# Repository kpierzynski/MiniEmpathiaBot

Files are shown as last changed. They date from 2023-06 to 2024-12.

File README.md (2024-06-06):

# RoboBond
## Empatyczny rój robotów

| Mobilny rój robotów |
|:-:|
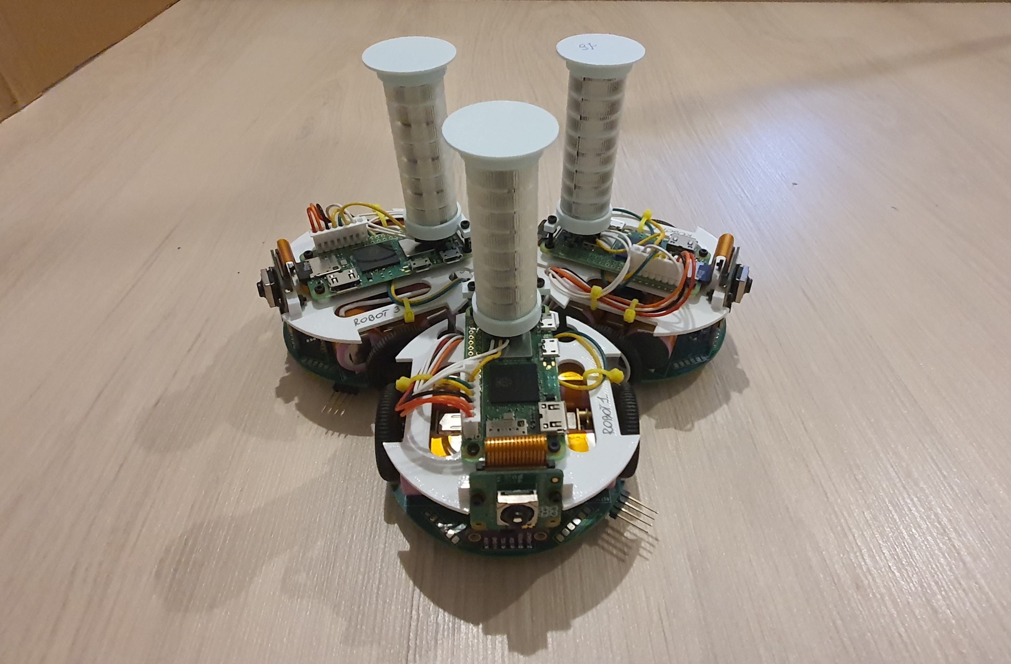
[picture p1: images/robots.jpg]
2nd_gen_robot
||

### Motywacja
Celem projektu jest opracowanie drugiej generacji empatycznego roju robotów, umożliwiającej przeprowadzanie fizycznych eksperymentów wygodniej, szybciej i na szerszą skalę. Celem badawczym jest analiza algorytmów sztucznej empatii na zminiaturyzowanej generacji roju robotów.

### Opis
Projekt "Rój Empatycznych Robotów" polega na stworzeniu zaawansowanej grupy robotów, która będzie zdolna do interakcji i współpracy, odzwierciedlając przy tym podstawowe instynkty ludzkie, aby efektywnie rozwiązywać zadane problemy. Przyjęcie perspektywy innej osoby i próba zrozumienia jej punktu widzenia znaczenie poprawia współpracę oraz wpływa na osiągnięte wyniki. Roboty dzięki modułowi sztucznej empatii, będą mogły podejmować decyzje w oparciu o stan sąsiednich robotów, pozwala to na stworzenie bardziej efektywnych strategii i szybsze osiągnięcie globalnego celu.

Do przeprowadzenia eksperymentów walidujących użycie algorytmów sztucznej empatii, stworzone zostały dwa symulatory oraz fizyczna platforma mobilnych robotów.

### Zastosowania
- Platforma badawcza dla naukowców do weryfikacji nowych algorytmów sztucznej empatii,
- Środowisko dla nauczycieli wspierające dydaktykę z zakresu sztucznej inteligencji,
- Infrastruktura do testowania nowych ścieżek automatyzacji i robotyzacji w przedsiębiorstwach,
- ... oraz wiele innych.

### Zawartość
W repozytorium znajdują się:
- Symulatory
    - `simulators/RL_ROS_Robots`
    - `simulators/Simpathy`
- Projekt mobilnych robotów
    - `kicad_workspace/bottom` - schemat elektroniczny PCB oraz opis konstrukcji
    - `code/STM32` - kod źródłowy dolnego niskopoziomowego mikrokontrolera robota
    - `code/PI` - kod źródłowy implementujący scenariusz empatyczny 
    - `cad_models` - modele 3d części robota

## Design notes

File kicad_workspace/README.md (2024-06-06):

# Empatyczny robot, iteracja druga

## Obecna konstrukcja PCB
Widok gory | Widok spodu
-- | --
top_view | bottom_view

## Architektura robota
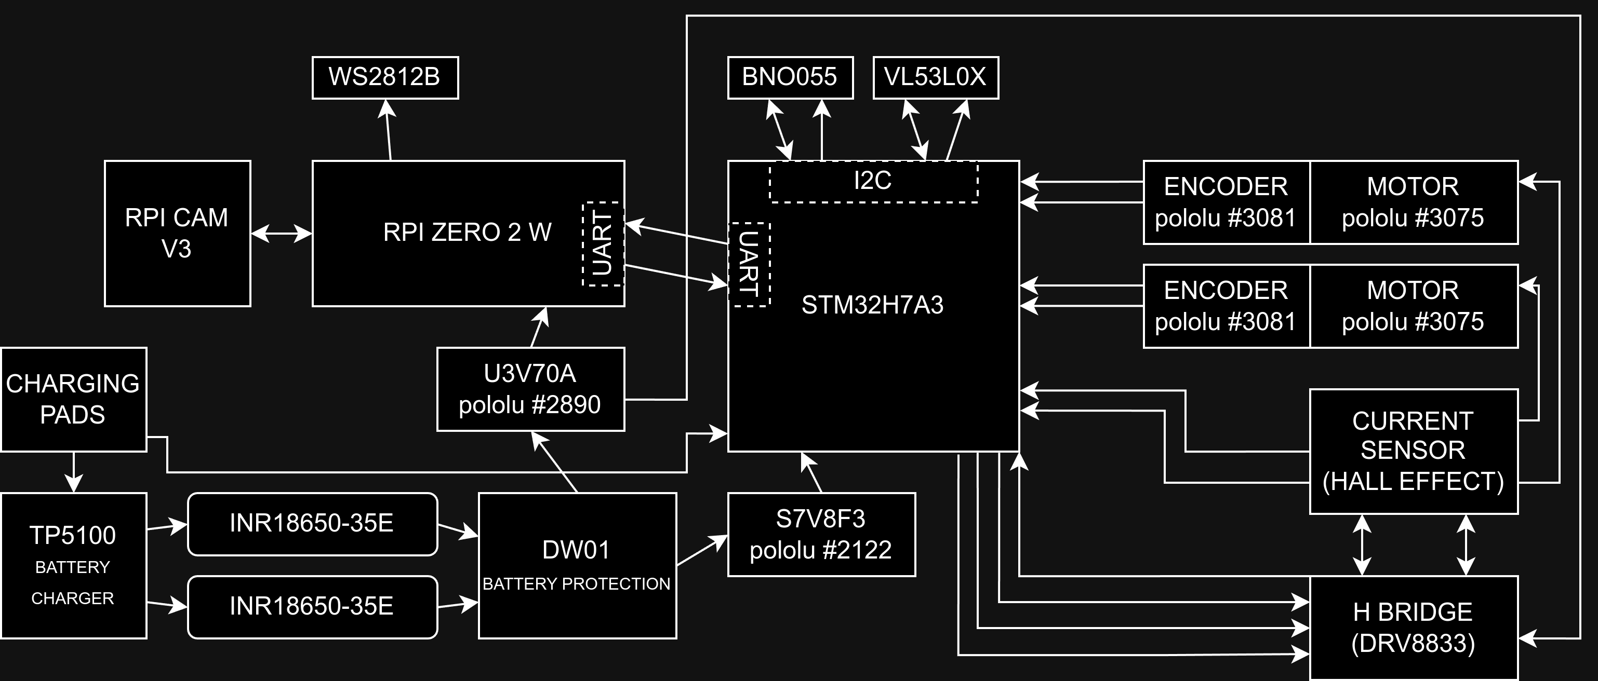
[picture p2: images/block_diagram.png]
block_diagram

Ze względu na minimalizację wymiarów robota, jego konstrukcja przewiduje dwie połączone nad sobą płytki drukowane. Dolna płytka będzie odpowiedzialna za interakcję z otoczeniem, a górna, za przetwarzanie informacji i podejmowanie decyzji. 

Poruszanie się robota w przestrzeni będzie realizowane przy pomocy dwóch miniaturowych silników z przekładniami firmy Pololu. Każdy z nich wyposażony jest w enkoder magnetyczny na bazie czujników efektu Hall’a TLE4946-2K, specjalnie zaprojektowanych do tego scenariusza. Obrót silników będzie dodatkowo nadzorowany przez czujniki prądu, jeden na każdy silnik, aby uzyskać dokładne sterowanie prędkością obrotową. W celu wyeliminowania strat na typowych czujnikach prądu z shunt resistor, można użyć układu, który mierzy prąd w oparciu o efekt Hall’a. Przykładem takich sensorów są ACS712 lub ACS724. Do zasilania silników jako układ wykonawczy zostanie wykorzystany DRV8833. Ten sterownik umożliwia obsługę dwóch silników i charakteryzuje się tym, że wymaga jedynie dwóch linii sterujących na silnik do regulacji prędkości i kierunku obrotu, a także jest prosty w obsłudze za pomocą sprzętowych Timer'ów w mikrokontrolerze. 

Aby zapewnić robotowi precyzyjną orientację w terenie, zostanie wyposażony w zintegrowany układ BNO055, składający się z akcelerometru, żyroskopu oraz magnetometru firmy Bosch. Układ ten będzie wspomagać algorytmy ruchu robota, aby osiągnąć maksymalną precyzję jego manewrów. Dodatkowo, sensory VL53L0X dostarczą informację o odległości przeszkód znajdujących się przed robotem. Zastosowanie tych sensorów wprowadza zwiększoną złożoność zarówno konstrukcji płytki, jak i algorytmów sterujących w porównaniu do tradycyjnych przycisków i krańcówek. Niemniej jednak ta zmiana przyczynia się do redukcji kontaktu mechanicznego z otoczeniem, co przekłada się na zminimalizowanie ryzyka uszkodzeń robota i zwiększenie jego niezawodności. 

Do zasilania robota zostaną wykorzystane dwa ogniwa litowo-jonowe INR18650-35E firmy Samsung o łącznej pojemności 7Ah. Ze względu na niewielkie rozmiary robota, w projekcie zostaną wykorzystane cylindryczne ogniwa zamiast płaskich baterii litowo-polimerowych, co wiąże się z koniecznością dodania układów zabezpieczających. Aby zapewnić bezpieczne zarządzani energią, zostanie wykorzystany układ ochrony baterii DW01 w połączeniu z tranzystorami wykonawczymi. Ten układ ma za zadanie monitorować napięcie baterii, aby nie przekroczyła dopuszczalnego zakresu oraz odłączać napięcie w przypadku wystąpienia zwarcia. Proces ładowania będzie nadzorowany przez układ TP5100, który nie tylko dostarczy do dwóch amperów prądu, ale także zapewni, że proces ładowania ogniw przebiegnie zgodnie ze specyfikacją ładowania metodą constant current constant voltage (CC CV). Jednym z założeń projektu jest możliwość ładowania robota bez ingerencji człowieka. Aby to osiągnąć, na spodzie dolnej płytki drukowanej umieszone zostaną dwa pady kontaktowe. Przy ich użyciu, robot po najechaniu na specjalną stację ładowania będzie mógł ładować baterie. To rozwiązanie jest niezwykle proste, zajmuje niewiele miejsca oraz nie wprowadza strat w przekazywaniu energii. 

Robot, pomimo niewielkich rozmiarów, będzie wyposażony w układy wymagające dużego poboru prądu. Aby sprostać ich oczekiwaniom, w projekcie zastosowane będą dwie przetwornice. Jedną o napięciu wyjściowym 5V – U3V70A, która jest w stanie podać do 10A w szczycie zapotrzebowania nawet przez kilka sekund. Druga przetwornica, tym razem dla układów zasilanych napięciem 3.3V - U7V8F3 będzie dostarczać prąd dla wszystkich czujników oraz mikrokontrolera. Warto zaznaczyć, że przetwornica 3.3V będzie pracować w dwóch trybach: step-down, gdy bateria będzie naładowana i step-up, gdy bateria będzie bliższa rozładowaniu.  

Na dolnej płytce umieszczony będzie również 32-bitowy mikrokontroler z rodziny STM32. Wysoka moc obliczeniowa, elastyczność i popularność pozwoli na implementację niemal dowolnie skomplikowanych algorytmów. Będzie on kontrolować wszystkie powyższe układy oraz komunimować się z głównym procesorem robota. 

Rolę mózgu urządzenia będzie pełnić Raspberry Pi Zero 2 W, jest to czterordzeniowy, jednopłytkowy komputer umieszczony na górnej płytce drukowanej, który z pomocą kamery Raspberry Pi Cam V3 będzie reagować na swoje otoczenie i inne roboty. Wszystkie algorytmy sztucznej inteligencji i empatii będą realizowane właśnie na tym mikrokomputerze. Sygnalizacja własnego wewnętrznego stanu będzie osiągana przez indywidualnie adresowalne diody RGB - WS2812B, ułożone w 8 rzędów, każdy po 3 diody. Umożliwi to wyświetlenie co najmniej półtora miliona różnych stanów. 

## Wstępne rozważania na temat wymagań konstrukcyjnych
- **Konstrukcja**

Robot będzie miał średnicę około 8 cm. Będzie złożony z dwóch płytek PCB, połączonych w 'kanapkę'. Dolna płytka (STM32 lub AVR) będzie odpowiadała za sterowanie silnikami itp, a górna (Rpi) od obliczenia i obsługę kamery.
Pojazd będzie wyposażony w krańcówki (switch) (około cztery sztuki) wokół swojej obudowy, aby wykrywać zderzenia z otoczeniem.

| Góra | Bok |
| --- | --- |
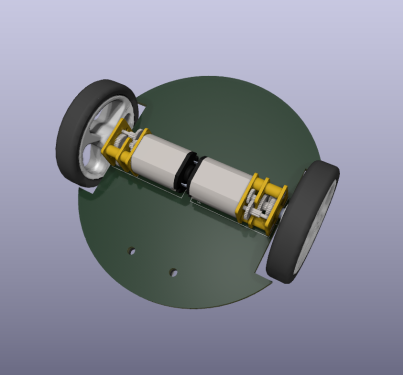
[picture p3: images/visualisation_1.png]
Góra
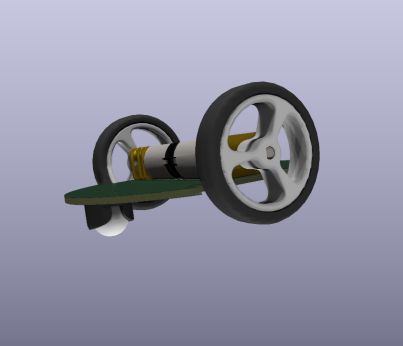
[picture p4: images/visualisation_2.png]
Bok
|  |  |

- **Sterowanie**

Za sterowanie czujnikami, silnikami itp. będzie odpowiedzialny mikrokontroler STM32 lub AVR. Z kolei za obsługę kamery będzie odpowiadał moduł Rasberry Pi Zero v2.

- **Napęd**

Robot będzie poruszał się z wykorzystaniem silników DC z enkoderami, aby umożliwić dokładne pomiary pojazdu. Niezbędny do tego będzie również sterownik silników, który w raz z enkoderami będzie sterowany przez STM. Dobór odpowiedniego przełożenia silnika wymaga ustalenia z jaką prędkością powinien poruszać się robot.

| Koła | Tylne koło | Silnik z enkoderem |
| --- | --- | --- |
| Koło | Tylne koło | Silnik |

- **Kamera**

Kamera będzie osadzona statycznie przy wieży LED. Serwomechanizm dodaje niepotrzebną złożoność, robot może obrócić się cały, aby wykonać zdjęcie.

- **LED**

Wieża LED oparta będzie o diody WS2812B (lub kompatybilne), w ośmiu rzędach, po dwie lub trzy diody.

- **Zasilanie**

Do zasilania pojazdów można zastosować cylindryczną baterie litowo jonową 18650 osadzoną w środku wieży LED, lub baterię litowo polimerową. W obu przypadkach wymagany będzie jeszcze układ ładowania ogniwa.
Aby uzyskać napięcie zasilania 5V, należy zastosować przetwornicę. Możliwości są dwie: 
    - przetwornica podwyższająca napięcie
        - niższa sprawność
        - jedno ogniwo, stąd prostszy układ ładowania ogniw
    - przetwornica obniżająca napięcie
        - wyższa sprawność
        - dwa lub więcej ogniw, bardziej skomplikowany układ ładowania

| | Li-ion 18650 | Li-Po |
| --- | --- | --- |
| Zalety | Wydajność prądowa (nawet 30A) | Wydajne prądowo ogniwa są zazwyczaj duże |
| Zalety | Tania | Gotowe zabezpieczenie przeciw rozładowaniu |
| Zalety | Prosta wymiana w razie potrzeby | Płaska |
| Wady | Podwyższa środek ciężkości | Trudno dostępna o wymaganych parametrach |
| Wady | Wymaga modyfikacji wieży | Wymiary ograniczają możliwości |
| Wady | Wymaga dodatkowego układu zabezpieczającego | - |

| Li-ion 18650 | Li-Po |
| --- | --- |
| Ogniwo 18650 | Ogniwo LiPo |

- **Ładowanie**

Do ładowania robotów zostaną wykorzystane pady kontaktowe, które będą w odpowiedni sposób wykrywane przez pojazdy. Do wypozycjonowania pojazdu względem padów można zastosować magnesy neodymowe, które naprowadzą robota wprost na pady. Pady kontaktowe mogłyby znajdować się pod obudową lub na jej boku.

- **Wybudzanie**

Mikrofon ultradźwiękowy, który ma ne celu wybudzenie robotów z trybu uśpienia. Jedna zewnętrzna płytka na arenie (np. ESP32/8266) będzie na stałe podłączona do internetu i będzie wyposażona w głośnik na ultradźwięki. Po otrzymaniu informacji po WiFi, wyemituje ona dźwięk, który wybudzi STM przez mikrofon, który z kolei wybudzi Rpi.
W przypadku niepowodzenia, można zastosować diody i fototranzystory/odborniki IR. 

- **Czujniki**

Warto wyposażyć robota w dodatkowe czujniki: *żyroskop*, *kompas* i *akcelerometr*. Umożliwią one dokładniejsze odnajdowanie się robota w przestrzeni.

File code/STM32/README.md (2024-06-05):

### EMPATHETIC
The project involves creating a control system for a two-wheeled robot using an STM32 microcontroller. The code handles four main components: motors, encoders, laser sensor and uart communication:

1. **Motors**: The STM32 microcontroller controls two DC motors using the DRV8833 motor driver. Pulse Width Modulation (PWM) is used to manage the speed and direction of the motors. The motors are controlled using a PID controller with an IIR filter for precise speed regulation and stability. The code includes functions for initializing PWM and adjusting motor parameters in real time.

2. **Encoders**: Each motor is equipped with a Hall-effect encoder that provides information about the speed and angular position of the wheels. The microcontroller receives signals from the encoders and converts them into speed and distance values. This data is used for precise movement control and to maintain a closed-loop feedback system.

3. **Laser Sensor**: The robot uses the VL53L0X laser sensor to detect obstacles and measure distances from objects. The project utilizes the ST library for handling the VL53L0X sensor. The data from the laser sensor is processed by the microcontroller, allowing the robot to avoid obstacles.

4. **UART Communication**: The program receives the desired speed information for each motor via UART, in the format 'LSXYZRSXYZ', where L stands for the left motor, R stands for the right motor, S is the sign (+ for positive, - for negative), and XYZ is the speed in rad/s, padded with leading zeros to three places. For example, to stop left motor, and spin right motor at 100rad/s, following string is used: 'L+000R+100'. 
UART config: 115200 8n1

The entire system is programmed in C, using the **HAL** (Hardware Abstraction Layer) library to handle the peripherals of the STM32 microcontroller. The code is modular, allowing for easy expansion and modification of individual functions.

CPU: STM32H7A3RITx
IDE: **STM32CubeIDE**, version: *1.15.0*
Dependencies:
- **CMSIS**, version *5.7.0*, (provides the implementation of digital filters): [link to download](https://www.keil.com/pack/ARM.CMSIS.5.7.0.pack)

To install CMSIS, in STM32CubeIDE nagivate to Help -> Manage Embedded Software Packages -> From Local... and select downloaded CMSIS pack.

### L152_ADC
Project mainly focused only on learning and testing stm32 platform
CPU: STM32L152RE
Objective: trigger ADC with TIMER using DMA

GPT-3.5 was used to improve above description

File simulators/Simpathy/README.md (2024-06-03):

# Simpathy - Simulator

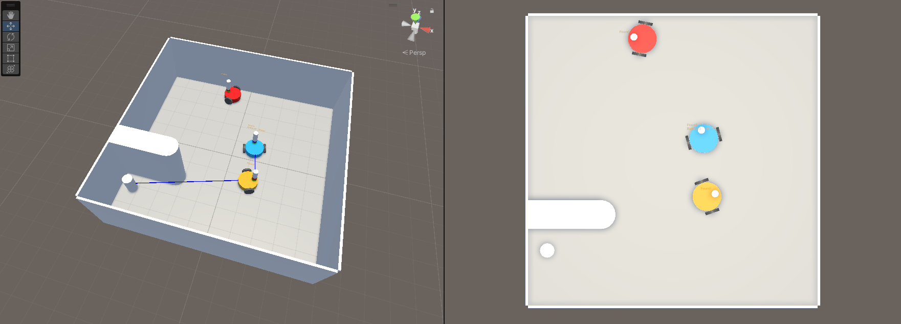
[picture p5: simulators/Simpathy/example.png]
"simulator"


The simulator, developed in Unity, offers an environment for comparing egotistic and empathetic behaviors of two-wheeled robots.

1. Environment: The simulation provides a straightforward arena and a customizable number of robots.
2. Robots: The agents' appearance and movement are modeled after real robots, aiming to mimic their core features. Agents communicate using a virtual camera and a tower constructed with rows of LEDs.
3. Experiments: The simulation features a basic empathetic scenario in which robots attempt to reach a goal cylinder while communicating with each other.

This setup allows for the examination of both egotistic and empathetic behaviors in a controlled virtual environment.

## How to run
1. Install Unity Hub from the Unity website,
2. Install Unity 2022.3.28f1 through Unity Hub,
3. Import project in Unity Hub,
4. Open the project with version 2022.3.28f1 of an engine.

3D Engine: **Unity**, version *2022.3.28f1*

## How to Use
0. Open scene from Assets/Scenes.
1. (Optional) Turn off gizmos for TextMeshPro.
2. Customize the simulation:
    - Main Camera object -> Manager Script
        - Speed: Controls the speed of the simulation for faster results.
    - Robots object -> Robot Spawner Script
        - Robot Prefab: Blueprint of the robot to spawn.
        -  Plane: The object on which robots will spawn, distributed randomly across the bounding space.
        - Robot Count: Number of robots to spawn.
    - Robot Prefab -> Robot Script
        - Egoistic: controls the behavior of a swarm.
3. Press "Play" in Unity's editor.
4. Observe the results.
5. (Optional) Edit the Robot.cs script to change the robots' behavior.

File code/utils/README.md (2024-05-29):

## calibrate_camera
This script performs camera calibration by detecting [chessboard](https://static.wixstatic.com/media/dd11f9_a6f04e762a25471e878762136b992d24~mv2.png/v1/fill/w_740,h_742,al_c,q_90,usm_0.66_1.00_0.01,enc_auto/dd11f9_a6f04e762a25471e878762136b992d24~mv2.png) corners in multiple images taken on different angles and using them to calibrate the camera. Calibration is necessary for correcting lens distortions and improving the accuracy of metric measurements in images.

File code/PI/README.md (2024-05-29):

# Controller for Robots

## Overview
This program integrates hardware control with image processing to steer a robot based on visual markers and color detection. The robot uses a camera to detect Aruco markers and led towers, adjusts it's LED colors, and steers based on the processed visual inputs. Communication with the hardware is managed via a serial interface. All this is to implement empathetic behavior in reaching the marker.

## How to run

To run this program, `Raspberry Pi Zero 2 W` single board computer equiped with `Raspberry Pi Camera V3`is required, along with the robot's motorized lower section.

1. PI operating system: Raspberry Pi OS Lite (64-bit), a port of debian Bookworm
    - Download and open Raspberry Pi Imager from the Raspberry Pi website.
    - Choose `Raspberry Pi OS Lite (64-bit)`.
    - Select your SD card and click `WRITE`.
    - *(Optional)* Configure WiFi, change username and password.
    - Once complete, insert the SD card into your Raspberry Pi and power it on.

2. Update package lists and upgrade already installed packages:
```
sudo apt-get update
sudo apt-get upgrade
```

3. Change size of swap on the`Raspberry Pi Zero 2 W`, which has limited RAM:
    - Edit file `/etc/dphys-swapfile` to increase swap size to `2048 mb`
    - Restart computer `sudo reboot`

4. Enable the serial interface on the Raspberry Pi to communicate with motors controlled by the STM32 microcontroller in the lower part of the robot. Use `raspi-config` to configure the settings.

5. Install necessary system packages:
```
sudo apt-get install curl git python3 python3-pip python3-venv python3-libcamera btop tmux libpcap-dev python3-full
sudo apt-get install python3-picamera2 --no-install-recommends
```

6. Create Python's virtual environment:
```
python3 -m venv --system-site-packages VENV
```
Note parameter `--system-site-packages`

7. Using freshly created venv, install modules:
```
VENV/bin/python3 -m pip install adafruit-circuitpython-neopixel pyserial opencv-contrib-python
```

8. Part of code that controls LEDs: `WS2812b` require low level access to procesor registers, therefore it needs sudo access. Because of that, LEDs are controlled by separate program that communicate through socket (`AF_UNIX` type for interprocess communication in unix-like systems). To run LED server:
```
sudo VENV/bin/python neo_server.py
```

9. Application is ready to run:
```
VENV/bin/python3 main.py
```

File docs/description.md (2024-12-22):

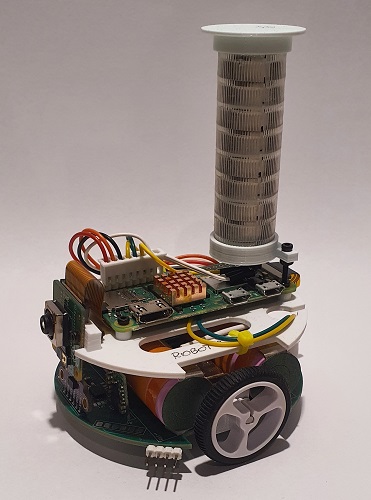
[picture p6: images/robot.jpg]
robot


# 0. Wstęp

Aktualne kody źródłowe znajdują się [tutaj](https://github.com/kpierzynski/MiniEmpathiaBot)

Wersja projektu PCB płytki, która została fizycznie wykonana w ramach projektu Empatycznych Robotów znajduje się w
`tag'u` [tutaj](https://github.com/kpierzynski/MiniEmpathiaBot/archive/refs/tags/v1.0_pcb.zip)

# 1. Budowa

## Opis

Ze względu na minimalizację wymiarów robota, jego konstrukcja przewiduje dwie połączone nad sobą płytki drukowane. Dolna
płytka będzie odpowiedzialna za interakcję z otoczeniem, a górna, za przetwarzanie informacji i podejmowanie decyzji.

Poruszanie się robota w przestrzeni jest realizowane przy pomocy dwóch miniaturowych silników z przekładniami firmy
Pololu. Każdy z nich wyposażony jest w enkoder magnetyczny na bazie czujników efektu Hall’a `TLE4946-2K`, specjalnie
zaprojektowanych do tego scenariusza. Obrót silników może być nadzorowany przez czujniki prądu, jeden na każdy silnik,
aby uzyskać dokładne sterowanie momentem silników. W celu wyeliminowania strat na typowych czujnikach prądu z shunt
resistor, zastosowano układ, który mierzy prąd w oparciu o efekt Hall’a. Przykładem takiego sensora jest `ACS712`,
natomiast jest on obecnie nieobsługiwany w oprogramowaniu dolnej płytki. Do zasilania silników jako układ wykonawczy
jest wykorzystywany `DRV8833`. Ten sterownik umożliwia obsługę dwóch silników i charakteryzuje się tym, że wymaga
jedynie dwóch linii sterujących na silnik do regulacji prędkości i kierunku obrotu, a także jest prosty w obsłudze za
pomocą sprzętowych Timer'ów w mikrokontrolerze `STM32`.

Aby zapewnić robotowi precyzyjną orientację w terenie, konstrukcja przewiduje zintegrowany układ `BNO055`, składający się
z akcelerometru, żyroskopu oraz magnetometru firmy Bosch. Układ ten może wspomagać algorytmy ruchu robota, aby osiągnąć
maksymalną precyzję jego manewrów, natomiast jest on obecnie nieobsługiwany przez oprogramowanie dolnej płytki.
Dodatkowo, sensor `VL53L0X` dostarcza informację o odległości przeszkód znajdujących się przed robotem. Zastosowanie
tego typu sensorów wprowadza zwiększoną złożoność zarówno konstrukcji płytki, jak i algorytmów sterujących w porównaniu do
tradycyjnych przycisków i krańcówek. Niemniej jednak ta zmiana przyczynia się do redukcji kontaktu mechanicznego z
otoczeniem, co przekłada się na zminimalizowanie ryzyka uszkodzeń robota i zwiększenie jego niezawodności.

Do zasilania robota wykorzystane są dwa ogniwa litowo-jonowe `INR18650-35E` firmy Samsung o łącznej pojemności `7Ah`.
Ze względu na niewielkie rozmiary robota, w projekcie zostaną wykorzystano cylindryczne ogniwa zamiast płaskich baterii
litowo-polimerowych, co wiąże się z koniecznością dodania układów zabezpieczających. Aby zapewnić bezpieczne zarządzanie
energią, użyto układ ochrony baterii `DW01` w połączeniu z tranzystorami wykonawczymi. Ten układ ma za
zadanie monitorować napięcie baterii, aby nie przekroczyła dopuszczalnego zakresu oraz odłączać napięcie w przypadku
wystąpienia zwarcia. Proces ładowania jest nadzorowany przez moduł `TP5100`, który nie tylko dostarczy do dwóch amperów
prądu, ale także zapewni, że proces ładowania ogniw przebiegnie zgodnie ze specyfikacją ładowania metodą constant
current constant voltage (`CC CV`). Czas ładowania wynosi około `4h`.
Jednym z założeń projektu jest możliwość ładowania robota bez ingerencji człowieka.
Aby to osiągnąć, na spodzie dolnej płytki drukowanej umieszone są dwa pady kontaktowe. Przy ich użyciu, robot
mógłby po najechaniu na specjalną stację, ładować baterie (brak implementacji w oprogramowaniu).

Robot, pomimo niewielkich rozmiarów, wyposażony jest w układy wymagające dużego poboru prądu. Aby sprostać ich
oczekiwaniom, w projekcie zastosowano dwie przetwornice. Jedną o napięciu wyjściowym `5V` – `U3V70A` (lub `U3V70F5` w
zależności od dostępności), która jest w
stanie podać do `10A` w szczycie zapotrzebowania nawet przez kilka sekund. Druga przetwornica, tym razem dla układów
zasilanych napięciem `3.3V` - `U7V8F3` dostarcza prąd dla wszystkich czujników oraz mikrokontrolera. Warto
zaznaczyć, że przetwornica 3.3V będzie pracować w dwóch trybach: step-down, gdy bateria będzie naładowana i step-up, gdy
bateria będzie bliższa rozładowaniu.

Na dolnej płytce umieszczony jest również 32-bitowy mikrokontroler z rodziny STM32 - `STM32H7A3RIT6`. Wysoka moc
obliczeniowa,
elastyczność i popularność pozwoli na implementację niemal dowolnie skomplikowanych algorytmów. Będzie on kontrolować
wszystkie powyższe układy na dolnej płytce oraz komunimować się z głównym procesorem robota.

Rolę mózgu urządzenia pełni `Raspberry Pi Zero 2 W`, jest to czterordzeniowy, jednopłytkowy komputer umieszczony
na górnej płytce, który z pomocą kamery `Raspberry Pi Cam V3` będzie reagować na swoje otoczenie i inne roboty.
Wszystkie
algorytmy sztucznej inteligencji i empatii będą realizowane właśnie na tym mikrokomputerze.

Sygnalizacja własnego wewnętrznego stanu osiągana jest przez indywidualnie adresowalne diody RGB - `WS2812B`, ułożone w 8
rzędów, każdy po 3 diody.

### Górna płytka składa się z:

- płytki `Raspberry Pi Zero 2 W`, na której znajduje się procesor przetwarzający obraz z kamery oraz uruchamia
  empatyczny kod;
- kamery `Raspberry Pi Cam v3`;
- `wieżyczki` komunikacyjnej, opartej na trzech listwach diod `WS2812B`, ułożonych do siebie tyłem. W ten sposób tworzą
  wieżyczkę z 8 rzędami, zdolnymi wyświetlać `RGB`;
- taśmy łączącej kamerę z `Rasbperry Pi`;
- złączem i wtyczką (z przewodami), służą one do połączenia z `dolną` płytką.

Zadaniem `górnej` płytki jest komunikacja z innymi robotami za pomocą `kamer` i `wieżyczek`, oraz wyświetlanie własnego
stanu za pomocą `wieżyczki`. Ponadto wykonywuje ona kod, który podejmuje decyzję na temat działań robota.

### Dolna płytka składa się z:

- mikrokontrolera STM `STM32H7A3`, który odpowiedzialny jest za sterowanie silnikami, odbieranie danych z czujników i
  komunikację z `górną` płytką;
- układu `DRV8833` - wykonawczy układ sterowania silnikami;
- dwóch układów `ACS712`, czujnikami poboru prądu przez silniki. (obecnie nie są one wykorzystywane);
- dwóch ogniw `INR18650-35E` (baterie zasilające robota);
- układu `TP5100` - ładowarki do ogniw;
- układu `DW01` wraz z czterema tranzystorami `8205A` typu MOSFET;
- przetwornicy `U3V70A` lub `U3V70F5` (w zależności od dostępności) - służy do zasilania silników, czujników oraz
  `górnej` płytki;
- prztwornicy `U7V8F3` do zasilania mikrokontrolera `STM` oraz czujników;
- czujnika `VL53L0X` oferujący laserowy pomiar odległości;
- dwóch silników `N20 100:1 HPCB 6V z wydłużonym wałem` (można wybrać nieznacznie inne przełożenie przekładni);
- dwóch enkoderów magnetycznych do oceny kierunku oraz prędkości obrotowej silników;
- modułu `BNO055` - układ zawierający akcelerometr, żyroskop i magnetometer (obecnie nieużywany);
- wyłącznika, odcinającego ogniwa od reszty układów;
- dwóch głównych kół oraz kółko tylne, wspierające stabilność;
- przewodów, wtyczek i złącz;
- kondensatorów, rezystorów i tym podobnych elementów pasywnych;
- autorskiej płytki `PCB`, która łączy elektrycznie wszystkie powyższe elementy.

Zadaniem `dolnej` płytki jest kontrola silników, odbiór danych z czujników oraz nasłuchiwanie komend z `górnej` płytki
oraz informowanie jej o stanie czujników.

### Ładowanie

Ładowanie odbywa się poprzez przyłożenie prądu poprzez pady kontaktowe od spodu dolnej płytki, o parametrach `5V` i
minimum `2.1A`. Należy pamiętać, że robot musi być wtedy włączony (natomiast sama płytka `Raspberry Pi Zero 2 W` może
zostać wyłączona poprzez komendę `shutdown now` wysłaną z terminala). Dla ułatwienia, przygotowany został prosty
projekt manualnej ładowarki, na którą można nałożyć robota:
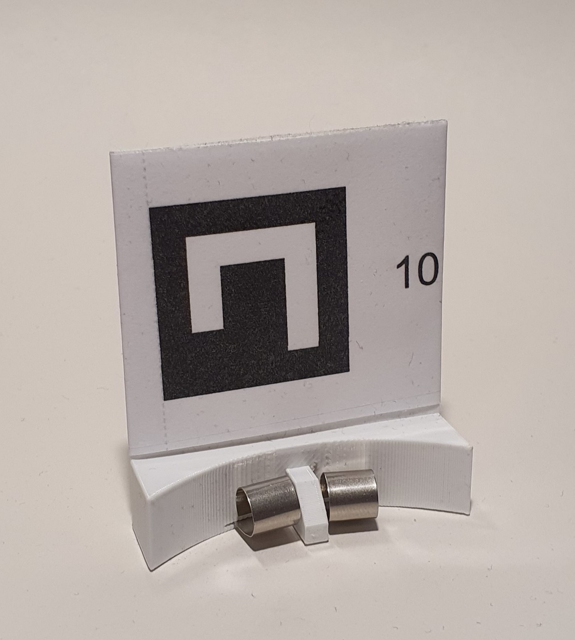
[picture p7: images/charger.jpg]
charger


### Uwagi

- Odwrotne połączenie baterii do złącza dolnej płytki skutkuje uszkodzeniem robota
- Odwrotne przyłożenie napięcia zasilania do padów ładujących może skutkować uszkodzeniem robota
- Warto przyłożyć mały wiatraczek w pobliżu robota podczas jego ładowania (opcjonalne, ale zalecane)
- Podłączenie zasilania poprzez złącze `USB` na płytce `Raspberry Pi` może skutkować uszkodzeniem tej płytki, jak i
  całego robota
- Wyłączenie robota przełącznikiem, bez wcześniejszego programowego wyłączenia `Raspberry Pi` (z poziomu konsoli) może
  skutkować uszkodzeniem plików na karcie mikro SD i wymagać będzie ponownego wgrania systemu operacyjnego
- Pierwsze uruchomienie programu robota może skutkować niekontrolowanym ruchem silników, należy wtedy zewrzeć piny GND i
  NRST złącza programowania
- Jeśli robot się nie porusza, mimo poprawie włączonego programu, można przeprowadzić reset poprzez zwarcie pinów GND i
  NRST
- Uruchomienie programu do kontroli wieżyczki i programu głównego na raz można osiągnąć poprzez zastosowanie programu typu
  multiplekser, na przykład: `tmux` [wiki](https://en.wikipedia.org/wiki/Tmux)
- Układ zabezpieczający ogniwa bywa czasem 'nadgorliwy' i jeśli po włączeniu robota przełącznikiem nie włącza się,
  należy go wyłączyć i włączyć ponownie

## Schematy

Schemat ideowy architektury `dolnej` płytki:
---
idea
---
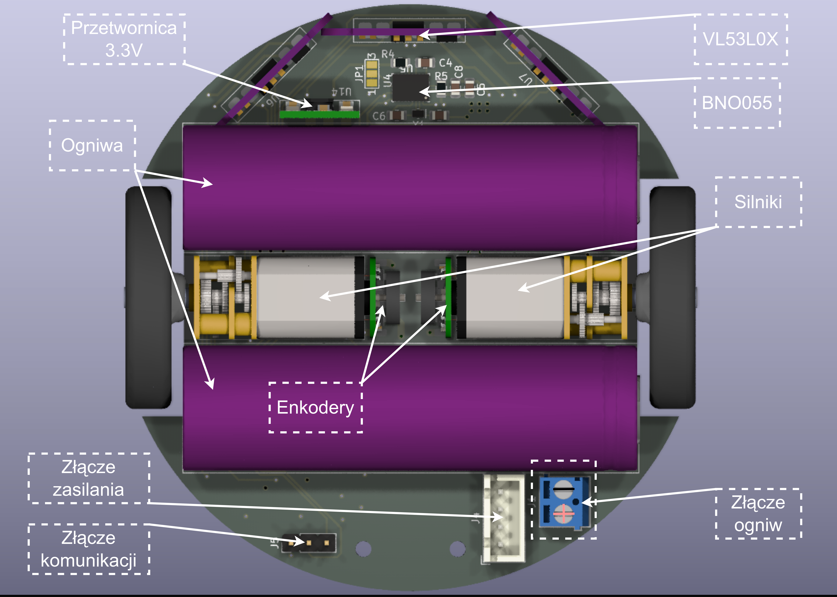
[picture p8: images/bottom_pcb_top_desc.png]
top

---
bot
---

## BOM (bill-of-material)

Wykaz potrzebnych układów scalonych:

`górna` płytka:

- 1x Raspberry Pi Zero 2
  W [przykład](https://botland.com.pl/moduly-i-zestawy-raspberry-pi-zero/20347-raspberry-pi-zero-2-w-512mb-ram-wifi-bt-42-5056561800004.html)
- 1x Raspberry Pi Camera
  V3 [przykład](https://botland.com.pl/kamery-do-raspberry-pi/22478-raspberry-pi-camera-hd-v3-12mpx-oryginalna-kamera-do-raspberry-pi-5056561803241.html)
- 1x Taśma
  kamery [przykład](https://botland.com.pl/tasmy-ffc-i-obudowy-do-kamer-do-raspberry-pi/8764-adapter-do-kamery-dla-raspberry-pi-zero-150mm-5904422372613.html)
- 1x Karta Micro SD na system do `Raspberry Pi`, minumum
  16gb [przykład](https://botland.com.pl/karty-pamieci-microsd-sd/17091-karta-pamieci-sandisk-microsd-32gb-80mbs-klasa-10-system-raspberry-pi-os-5903351247771.html)
- 3x Listwa LED
  WS2812 [przykład](https://botland.com.pl/lancuchy-i-matryce-led/6255-listwa-led-rgb-ws2812-5050-x-8-diod-53mm-5903351249157.html)
- 1x Listwa goldpin kątowa 2.54 (listwa 40 goldpinów kątowych starczy na 9
  robotów) [przykład](https://allegro.pl/oferta/wtyk-goldpin-1x40-katowy-raster-2-54mm-5-sztuk-15595405288)
- 1x Listwa goldpin prosta 2.54 (listwa 40 goldpinów prostych starczy na 4
  roboty) [przykład](https://allegro.pl/oferta/goldpin-listwa-prosta-1x40-2-54mm-2szt-7845727129)

`dolna` płytka:

- 1x Para kół
  POLOLU-1087 [przykład](https://botland.com.pl/kola-z-oponami/12-kola-32x7mm-czarne-pololu-1087-5903351247924.html)
- 1x Tylne koło
  POLOLU-951 [przykład](https://botland.com.pl/kulki-podporowe/63-ball-caster-38-metalowy-pololu-951-5904422362690.html)
- 1x Komplet enkoderów
  POLOLU-3081 [przykład](https://botland.com.pl/enkodery/4884-zestaw-enkoderow-magnetycznych-do-micro-silnikow-pololu-kompatybilne-z-hpcb-27-18v-2-szt-pololu-3081-5904422309763.html)
- 2x Silnik N20 6V 100:1, koniecznie z obustronnym wałem
  POLOLU-3075 [przykład](https://botland.com.pl/silniki-dc-micro-z-przekladnia/5095-silnik-hpcb-1001-obustronny-wal-pololu-3075-5904422306250.html)
- 1x Przetwornica 5V U3V70A POLOLU-2890 lub U3V70F5
  POLOLU-2891 [przykład 1](https://botland.com.pl/przetwornice-step-up/14009-u3v70a-przetwornica-step-up-regulowana-45-20v-10a-pololu-2890-5904422308278.html) [przykład 2](https://botland.com.pl/przetwornice-step-up/14003-u3v70f5-przetwornica-step-up-5v-10a-pololu-2891-5904422342333.html)
- 1x Przetwornica 3.3V
  S7V8F3 [przykład](https://botland.com.pl/przetwornice-step-up-step-down/1427-s7v8f3-przetwornica-step-up-step-down-33v-1a-pololu-2122-5904422373092.html)
- 2x Ogniwa INR18650-35E z
  blaszkami [przykład](https://allegro.pl/oferta/akumulator-li-ion-3-6v-3500mah-35e-18650-samsung-jakar-14648140021)
- 1x Moduł ładowania
  TP5100 [przykład](https://allegro.pl/oferta/ladowarka-bms-tp5100-1s-2s-4-2v-8-4v-2a-li-ion-12807445915)
- 1x Układ zabezpieczający
  DW01 [przykład](https://allegro.pl/oferta/uklad-scalony-dw01a-sot23-ochronna-baterii-litowej-14329551443)
- 4x MOSFET wykonawczy 8205A (w obudowie TSSOP8) (najprościej pozyskać z
  wylutu) [przykład](https://allegro.pl/oferta/modul-bms-1s-12a-15a-li-ion-18650-3-7v-ladowarka-8727193369)
- 1x BNO055 !opcjonalny, aktualnie
  niewykorzystywany! [przykład](https://www.mouser.pl/ProductDetail/Bosch-Sensortec/BNO055?qs=QhAb4EtQfbV8Z2YmISucWw%3D%3D)
- 3x VL53L0X !dwa są opcjonalne, aktualnie
  niewykorzystywane! [przykład](https://allegro.pl/oferta/czujnik-odleglosci-vl53l0x-laser-technologia-tof-11615057637)
- 1x Złącze ARK 3.5mm 2-pinowe
  gniazdo [przykład](https://allegro.pl/oferta/zlacze-ark-3-5-2-pin-do-druku-250v-10a-5-sztuk-16363325265)
- 1x
  Wyłącznik [przykład](https://allegro.pl/oferta/przelacznik-dzwigienkowy-1a-3-pin-2-pozycje-0924-10562437231?fromVariant=11672438745)
- 1x Złącze JST-XH 4-pinowe gniazdo

- 2x ACS712-05B (wersja do 5A) !opcjonalny, aktualnie niewykorzystywany! (obudowa
  SOIC8) [przykład](https://allegro.pl/oferta/modul-ukladu-czujnika-halla-acs712-5a-pcb-pomiar-pradu-z-esp-arduino-avr-16710090918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)
- 1x DRV8833PWP (obudowa HTSSOP-16) [przykład](https://www.mouser.pl/ProductDetail/595-DRV8833PWP)
- 1x STM32H7A3RIT6 (obudowa LQFP64) [przykład](https://www.mouser.pl/ProductDetail/511-STM32H7A3RIT6)

- 2x Kondensator 0805 22pF (niepotrzebny, jeśli brak BNO055)
- 1x Kondensator 0805 120nF (niepotrzebny, jeśli brak BNO055)
- 13x Kondensator 0805 100nF
- 4x Kondensator 0805 1uF
- 3x Kondensator 0805 2.2uF
- 2x Kondensator 0805 10nF
- 1x Kondensator 0805 10uF
- 1x Kondensator tantalowy 100uF (około, ale lepiej więcej) 6.3V minimum, obudowa B (1411)

- 1x Dławik ferrytowy 0805 470nH (około)

- 2x Rezystor 0805 0R (4x jeśli brak ACS712)
- 9x Rezystor 0805 10K
- 1x Rezystor 0805 33K
- 2x Rezystor 0805 5.6K (niepotrzebny, jeśli brak BNO055)
- 1x Rezystor 100R
- 1x Rezystor 1K

ogólne:

- 1x Złącze JST-XH 4-pinowe wtyk
- 1x Złącze JST-XH 8-pinowe wtyk
- 1x Złącze JST-XH 3-pinowe wtyk
- 16x Pin JST-XH
- Przewód połączeniowy ogniw (AWG18-19)
- Przewód połączeniowy złącz JST (AWG22-26, najlepiej 24, najlepiej kilka kolorów)

- 1x !jeden zestaw starczy na kilka robotów! Zestaw śrubek
  M2 [przykład](https://allegro.pl/oferta/zestaw-srub-nakretek-metalowych-m2-420-sztuk-jakar-14384052335)
- cyna 0.56mm +- 0.16mm
- około 10cm taśmy niklowej (do wykonania połączeń przy silnikach)
- około 15cm taśmy niklowej (opcjonalnie) (do wykonania ładowarki)

# 2. Uruchomienie

## `górna` płytka - uruchomienie:

**Do wykonania poniższych kroków niezbędna jest podstawowa znajomość systemu Linux oraz ekosystemu Raspberry**

1. Instalacja systemu `Raspberry Pi OS Lite (64-bit), port Debiana Bookworm`

- Pobierz i uruchom Raspberry Pi Imager ze strony Raspberry Pi.
- Wybierz „Raspberry Pi OS Lite (64-bit)”.
- Wybierz kartę SD i kliknij „WRITE”.
- Skonfiguruj WiFi, zmień nazwę użytkownika i hasło, włącz SSH.
- Po zakończeniu włóż kartę SD do Raspberry Pi.

2. Uruchom `Raspberry Pi` i podłącz się do konsoli po SSH (lub za pomocą monitora przez HDMI i klawiatury przez USB)
3. Po otworzeniu konsoli i zalogowaniu się:

- Zaktualizuj listy pakietów i zainstaluj aktualizacje dla już zainstalowanych pakietów:

```bash
sudo apt-get update
sudo apt-get upgrade
```

- Zmień rozmiar przestrzeni wymiany (swap) na „Raspberry Pi Zero 2 W”, który ma ograniczoną pamięć RAM:
    * Edytuj plik `/etc/dphys-swapfile`, aby zwiększyć rozmiar swap do `2048 MB`.
    * Zrestartuj `Raspberry` za pomocą `sudo reboot`.
- Włącz interfejs szeregowy na Raspberry Pi, aby móc komunikować się z silnikami sterowanymi przez mikrokontroler STM32
  w dolnej części robota. Użyj narzędzia `raspi-config` do konfiguracji ustawień.
- Zainstaluj niezbędne pakiety systemowe:

```bash
sudo apt-get install curl git python3 python3-pip python3-venv python3-libcamera btop tmux libpcap-dev python3-full
sudo apt-get install python3-picamera2 --no-install-recommends
```

- Utwórz wirtualne środowisko Pythona:

```bash
python3 -m venv --system-site-packages VENV
```

**Uwaga na parametr `--system-site-packages`**

- Używając świeżo utworzonego środowiska venv, zainstaluj moduły:

```bash
VENV/bin/python3 -m pip install adafruit-circuitpython-neopixel pyserial opencv-contrib-python
```

- Część kodu sterującego diodami LED: `WS2812` wymaga niskopoziomowego dostępu do rejestrów procesora, dlatego wymaga
  dostępu sudo. Z tego powodu diody LED są sterowane przez osobny program komunikujący się za pomocą gniazda (`AF_UNIX`
  typ do komunikacji międzyprocesowej w systemach podobnych do Unix). Aby uruchomić serwer LED:

```bash
sudo VENV/bin/python neo_server.py
```

**Uruchomienie podprogramu do obsługi diod LED oraz głównej części aplikacji wymaga dwóch terminalów, można skorzystać
z `tmux`.**

- Aplikacja jest gotowa do uruchomienia:

```bash
VENV/bin/python3 main.py
```

## `dolna` płytka - uruchomienie:

1. Pobierz `STM32CubeIDE` w wersji
   `1.15.0` [link](https://www.st.com/en/development-tools/stm32cubeide.html#get-software)
2. Zainstaluj `IDE` zgodnie z krokami instalatora
3. Do skompilowania projektu potrzebna jest również biblioteka `CMSIS` w wersji
   `5.7.0` [dostępna tutaj](https://www.keil.com/pack/ARM.CMSIS.5.7.0.pack)

- W oknie `IDE` przejdź do `Help`, dalej wybierz `Manage Embedded Software Packages`, następnie przycisk `From Local...`
  i wybierz wyżej pobrany pakiet `CMSIS`.

4. Otwórz projet i wgraj go na mikrokontroler `STM` za pomocą padów wyprowadzonych na krawędzi `dolnej` płytki.

- Do zaprogramowania potrzebne są połączenia czterech przewodów między `STM` a programatorem:
    * NRST
    * SWDIO
    * GND
    * SWCLK
- Należy użyć oryginalnego programatora `ST-link` od firmy `ST`

Dolna `płytka` komunikuje się z `górną` przy pomocy protokołu `UART` w konfiguracji `115200 8n1`, oczekuje ona nastawy
prędkości silników w następującej postaci:

```uart
LsXYZsXYZ
```

, gdzie `L` to dosłownie litera L oznaczająca, że następne dane konfigurują silnik L (analogicznie `R`), `s` to znak (
kierunek) obrotu silnika ze zbioru `+-`, a XYZ to trzy cyfrowa liczba oznaczająca prędkość dla danego silnika

# 3. Łącznie z `górną` płytką

W obecnej chwili zarządzanie robotem odbywa się za pomocą konsoli Linux, do której podłączenie odbywa się przy pomocy
branżowego standardu poprzez protokuł `SSH`. Nazwa użytkownika ustalana jest w pierwszyk kroku podczas instalacji
systemu `Raspberry Pi OS Lite (64-bit), port Debiana Bookworm` w `Raspberry Pi Imager`. Analogicznie do nazwy
użytkownika, w `Imager` ustawiane jest hasło do tego użytkownia jak i parametry sieci `WiFi` do której ma łączyć się
robot. Wywołanie `SSH` może wyglądać następująco:

```bash
ssh [robot_username]@[robot_ip]
```

, gdzie `[robot_ip]` należy odnaleźć przy użyciu ustawień routera, do którego łączyć się będzie robot, lub programu typu
`Advenced Ip Scanner`.

# 4. System wizyjny

## Wieżyczki

(`detect_tower.py`)

System wizyjny jest rozwiązany w oparciu o bibliotekę `OpenCV`. Rozpoznawane są trzy typy wieżyczek:
`całkowicie czerwone`, `całkowicie zielone` oraz `całkowicie niebieskie`. Algorytm wykrywania działa w oparciu o
poniższe, główne kroki:

1. Pobranie z modułu kamery aktualnej ramki z obrazem
2. Podział ramki na trzy podramki (maski), wydzielając z obrazu trzy podstawowe kolory w oparciu o arbitralnie wybrane
   wartości graniczne (zdefiniowane w `detect_tower.py` jako zmienna słownikowa `hsv_ranges`)
3. Tak przefiltrowane względem intensywności koloru maski są łącznone w jedną ramkę
4. Na ramce wykonywane są operacje wykrywania wieżyczek
    * odrzucane są zbyt małe kształty, mało prawdopodobne kształy
    * wykonywane jest rozmycie ramki, aby wygładzić ostre filtrowanie z kroku 2.
5. Wieżyczki są zliczane i zapisywane do dalszego przetwarzania

Rozwiązanie to jest niestety podatne na zmienne warunki oświetlenia oraz ze względu na proces przetwarzania, podatne na
rozpoznawanie innych przedmiotów jako wieżyczki, natomiast wykonywane jest szybko, mimo niezbyt imponującej mocy
obliczeniowej procesora.

## ArUco

(`detect_aruco.py`)

Jako znacznik celu, wykorzystane są znaczniki ArUco, przypominające popularne QRCode. Ich przewagą jest możliwość (
relatywnie) prostego określenia odległości, rotacji i ich przesunięcia względem robota.

Aby osiągnąć dokładny pomiar odległości, należy wcześniej przeprowadzić kalibrację kamery i w efekcie odnaleźć macierz
kamery oraz współczynniki zniekształcenia. Macierz ta, jak i współczynniki są już znalezione i są w pliku `Camera.py`.
Warto zauważyć, że macierz jaki i współczynniki są różne, dla różnych kamer i rozdzielczości. Ponadto, rozmiar użytych
kodów musi być podany wcześniej w `detect_aruco.py` w zmiennej `marker_length` w metrach. Domyślnie `0.0355m` czyli
`3.55cm`.

Algorytm rozpoznawania ArUco z kamery działa następująco:

1. Wczytanie ramki z modułu kamery
2. Przekazanie jej do OpenCV solvera, które znajdzie kody na zdjęciu oraz określi ich przekształcenia i odległość na
   podstawie macierzy i wspólczynników kamery.
3. Przeliczenie odległości na `cm` oraz zapisanie każdego znalezionego kodu do dalszego przetwarzania.

# 5. Działanie

Program obecnie składa się z kroku inicjalizacji oraz pętli głównej.
W kroku inicjalizacji przygotowywane są komponenty:

- inicjalizacja listy wektoróœ celu
- inicjalizacja kamery wraz z parametrami (rozdzielczość 1280x720, obrót horyzontalny o 180 stopni)
- inicjalizacja modułu `UART` do komunikacji z `dolną` płytką
- inicjalizacja klienta, który łączy się z serwerem diod LED wieżyczki
- inicjalizacja stanu wewnętrznego robota

Dalej, w pętli głównej wykonywane są kroki:

1. Pobranie ramki z modułu kamery
2. Odebranie z `dolnej` płytki informacji o odległości robota od najbliższej przeszkody (na podstawie laserowego
   czujnika odległości VL53L0X)
3. Uruchomienie przetwarzania detekcji ArUco kodów na podstawie ramki z kamery
    * Uaktualnienie stanu robota o informacje o znajdujących się (lub nie) w pobliżu kodów ArUco
4. Uruchomienie przetwarzania detekcji wieżyczej innych robotów
    * Uaktualnienie stanu robota o informacje o otaczających go robotach
5. Ewaluacja wewnętrznego stanu robota względem wektorów celu przy pomocy rozmytej funkcji podobieństwa
    * Odnalezienie najbardziej podobnego wektora do wektora wewnętrznego
    * Sprawdzenie, czy podobieństwo przekracza próg
        - jeśli tak, to podejmowana jest akcja związana z tym wektorem
        - jeśli nie, robot porusza się losowo.

Wektory celu dla scenariusza poszukiwania ArUco wyglądają następująco:

```python
GOALS = {
    "aruco": [1, 0.2, 0.5, 0.5, 1],
    "teamwork": [0, 1, 0.8, 0.8, 0]
}
THRESHOLD = 0.8
```

, gdzie:

| i-ty element | funkcja |
|---|---|
| v_1 | czy robot widzi cel? (0 jeśli nie, 1 jeśli tak) |
| v_2 | dystans do ArUco (w metrach, gdzie wartości >1m są zaokrąglane w dół do 1) |
| v_3 | czy robot widzi jakiegoś zielonego robota? (1 jeśli tak, 0 jeśli nie) |
| v_4 | czy robot widzi innego niebieskiego robota? (1 jeśli tak, 0 jeśli nie) |
| v_5 | czy robot jest aktualnie zielony? (inaczej: czy robot widzi cel?) (1 jeśli tak, 0 jeśli nie) |

Dobierając różne wartości wektorów celu lub/i dodając nowe, można zmienić sposób działania poszczególnych robotów jak i
całego roju.

Akcje, które mają się wykonać po spełnieniu wszystkich warunków dla danej akcji zdefiniowane są na końcu pętli głównej w
bloku `match`. W przykładowym kodzie, są dwie akcje związane z dwoma wektorami celu oraz dodatkowa 'domyślna' akcja
jeśli żaden z wektorów nie spełni warunków. W przypadku spełnienia wektora celu o nazwie `aruco` robot zapali wieżyczkę
na zielono oraz rozpocznie jazdę w kierunku pierwszego kodu. W przypadku akcji wektora `teamwork`, robot zapali się na
niebiesko i zacznie podążać do pierwszego znalezionego robota, który widzi cel lub innego robota, który widzi cel.
Domyślna akcja powoduje, że robot porusza się losowo po środowisku.

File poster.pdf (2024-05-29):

pierwsza generacja | nowa generacja
nieprecyzyjne poruszanie się spowodowane niską jakością silników oraz niedoskonałą metodą sterowania | ulepszone sterowanie dzięki czujnikom poboru prądu oraz użycie precyzyjnych silników
przewodowe ręczne ładowanie | bezprzewodowe automatyczne ładowanie
niska pojemność baterii - krótki czas pracy | wydajna bateria o 75% większej pojemności
obiektyw niskiej jakości o zbyt dużych wymaganiach co do oświetlenia | kamera o większej rozdzielczości, z większym kątem widzenia oraz szerszą rozpiętością kolorów

# EMPATYCZNY RÓJ ROBOTÓW

Celem projektu jest opracowanie drugiej generacji empatycznego roju robotów, umożliwiającej

## przeprowadzanie fizycznych eksperymentów wygodniej, szybciej i na szerszą skalę. Celem

badawczym jest analiza algorytmów sztucznej empatii na zminiaturyzowanej generacji roju robotów.

# Model empatii

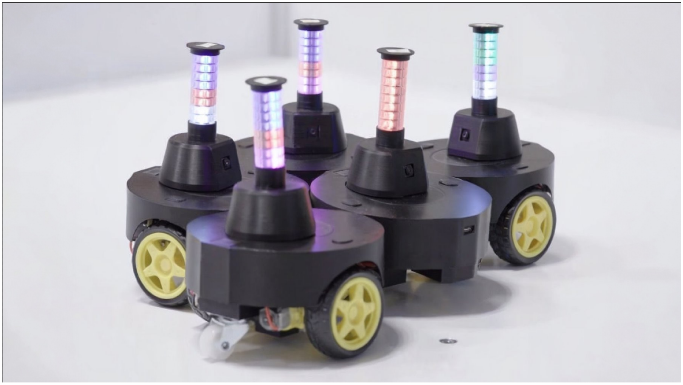
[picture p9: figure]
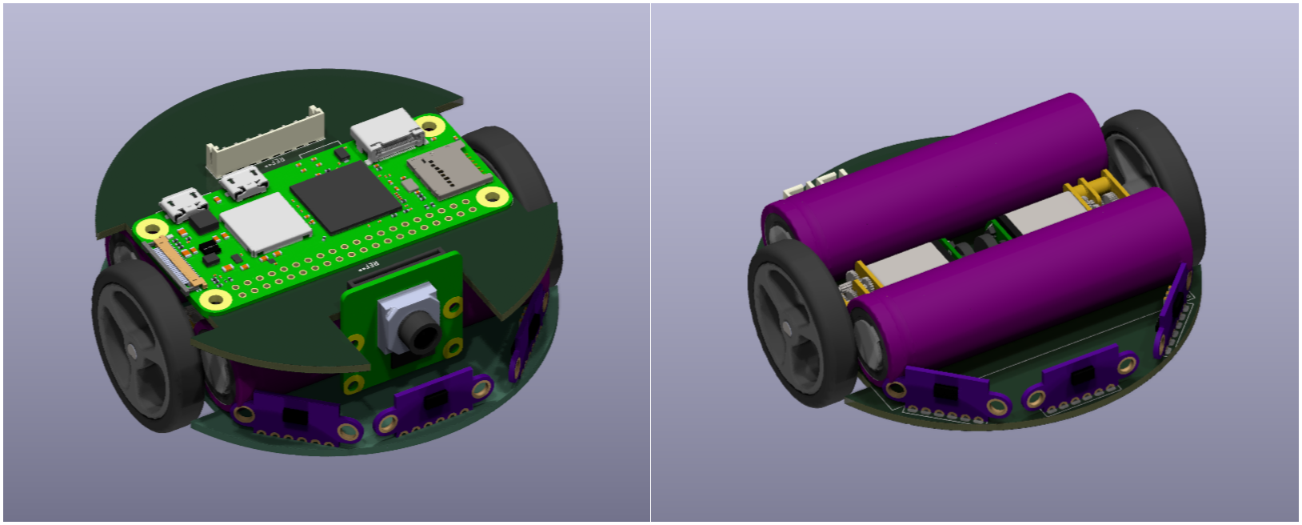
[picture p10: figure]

# Zastosowania

Platforma badawcza dla naukowców do weryfikacji nowych algorytmów sztucznej empatii
Środowisko dla nauczycieli wspierające dydaktykę z zakresu sztucznej inteligencji
Infrastruktura do testowania nowych ścieżek automatyzacji i robotyzacji w przedsiębiorstwach

Ponadto, roboty będą wyposażone również w: kompas oraz żyroskop do lepszej orientacji w przestrzeni,
czujniki odległości wspomagające unikanie kolizji,
moduł zdalnego wybudzania,
mikrokontroler STM32, który odciąży główny procesor od zarządzania silnikami i czujnikami,
wieżyczkę stanów o poprawionych kątach widoczności,
autorską płytkę PCB;

## Konrad Pierzyński, Yevhenii Poliakov, Adrian Szczeszek, Witold Woch

Rys. 1. Pierwsza generacja

Rys. 2. Nowa generacja poprawionych, zminiaturyzowanych robotów

# Specyfikacja

# Wizualizacja

Projekt dofinansowany z
Study@Research

# Literatura

Siwek, J.; Żywica, P.; Siwek, P.; Wójcik, A.; Woch, W.; Pierzyński, K.; Dyczkowski, K. Implementation of an Artificially Empathetic Robot Swarm. Sensors 2024, 24, 242. https://doi.org/10.3390/s24010242
M. Rubenstein, C. Ahler and R. Nagpal,

"Kilobot: A low cost scalable robot system for collective behaviors,

" 2012 IEEE International Conference on Robotics and Automation, Saint Paul, MN, USA, 2012, pp. 3293-3298, doi: 10.1109/ICRA.2012.6224638.
Yalçın, Ö.N., DiPaola, S. Modeling empathy: building a link between affective and cognitive processes. Artif Intell Rev 53, 2983–3006 (2020). https://doi.org/10.1007/s10462-019-09753-0

# Metodyka badań

przeprowadzenie eksperymentów na fizycznej platformie z udziałem nowej generacji empatycznego roju robotów,
realizacja symulacji w wirtualnym środowisku do badań empatycznych algorytmów

Empatia to umiejętność wczuwania się w stan drugiej osoby, po to, by móc ją zrozumieć i się od niej uczyć. Podczas kooperacji pozwala przewidzieć zachowania innych jednostek i odpowiednio planować własne działania, by osiągnąć globalny cel. Jest to niezwykle cenna umiejętność pozwalająca na efektywną pracę w grupach, którą warto przenieść na sztuczne systemy, takie jak roje. Podstawowym elementem sztucznej empatii jest porównywanie własnej wiedzy ze stanem wewnętrznym innego agenta, stąd kluczową rolę odgrywa tu komunikacja. Podobnie jak u ludzi, wymiana informacji między sobą jest procesem nieprecyzyjnym. W związku z tym do opisu tych informacji naturalnym wyborem jest zastosowanie zbiorów rozmytych. Do porównania własnej wiedzy z otrzymanym stanem wewnętrznym innego agenta można użyć podanej miary podobieństwa zbiorów rozmytych:

Agenci są wyposażeni w dwa moduły decyzyjne: egoistyczny oraz empatyczny. Pierwszy z nich odpowiada za działania, które przybliżają agenta do lokalnego celu. Drugi zapewnia akcje osiągające ten sam cel, ale w synergiczny sposób. Podczas interakcji między robotami, ewaluowane są nagrody za działania z obydwu modułów. Finalna decyzja zależy od porównania, która ze strategii jest bardziej opłacalna. Nagrody obliczane są na podstawie wzoru:

W tym przypadku oznacza liczbę stanów, natomiast pary to nagrody przechowywane w pamięci.

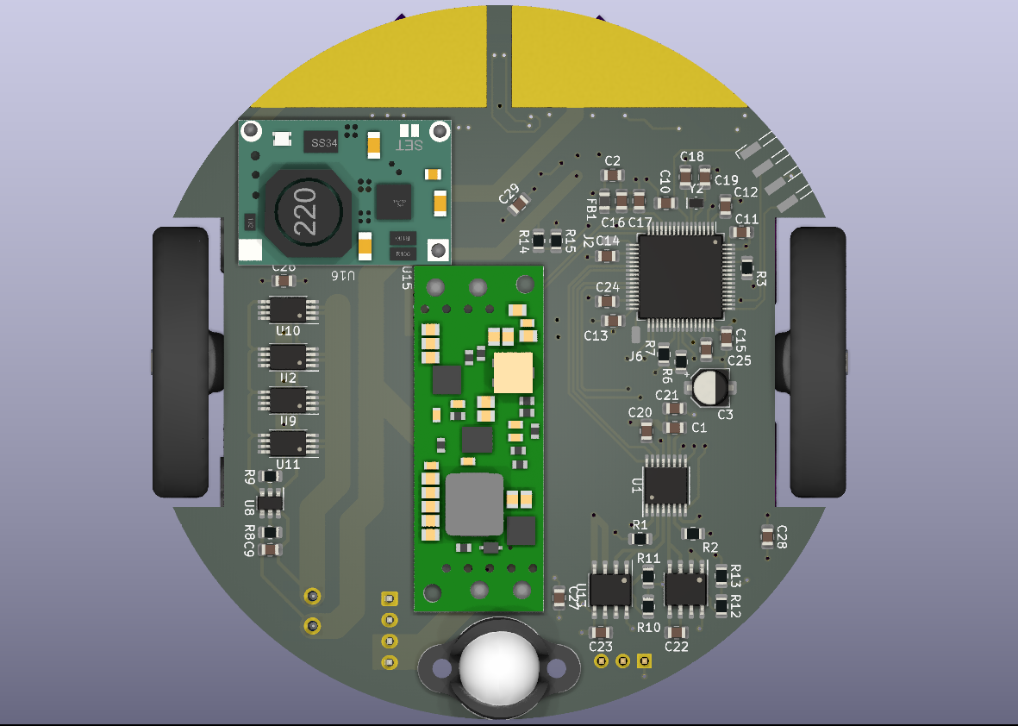
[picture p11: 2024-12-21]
images/bottom_pcb_bot_raw.png

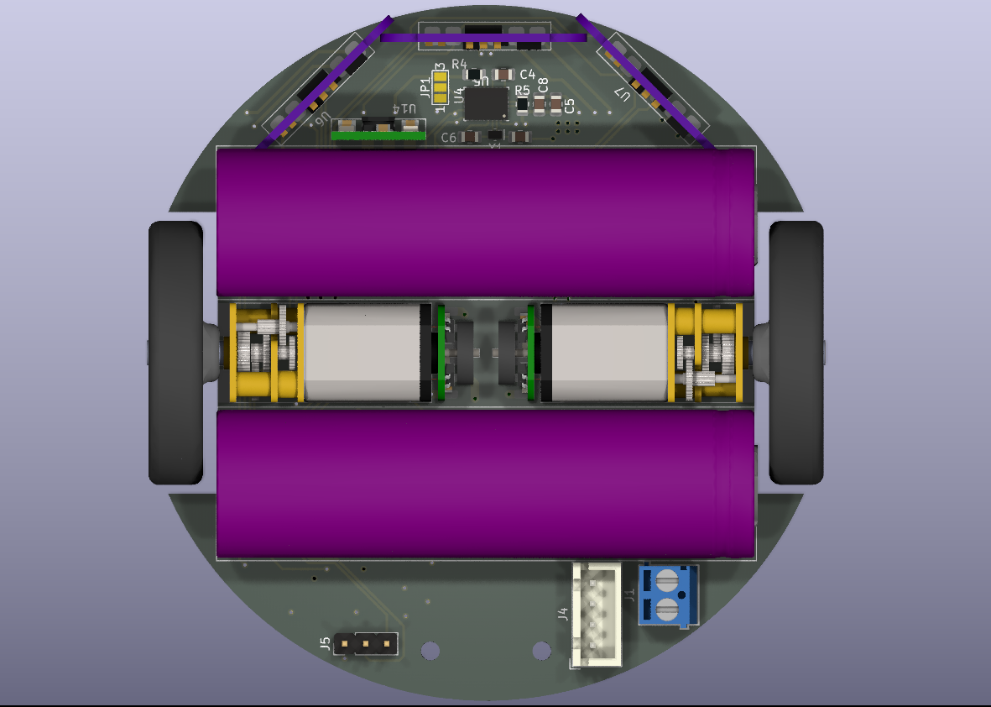
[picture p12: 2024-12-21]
images/bottom_pcb_top_raw.png

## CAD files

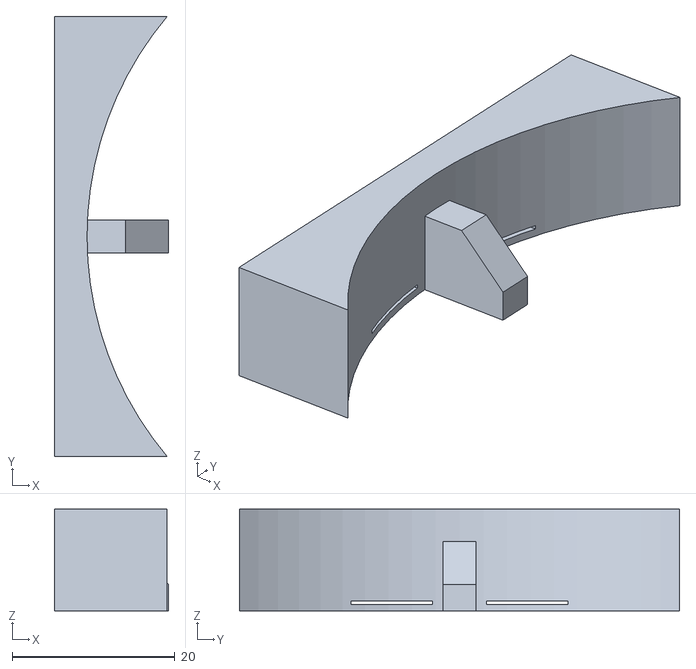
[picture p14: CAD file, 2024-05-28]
cad_models/charger.stl
14.0 x 54.0 x 12.5

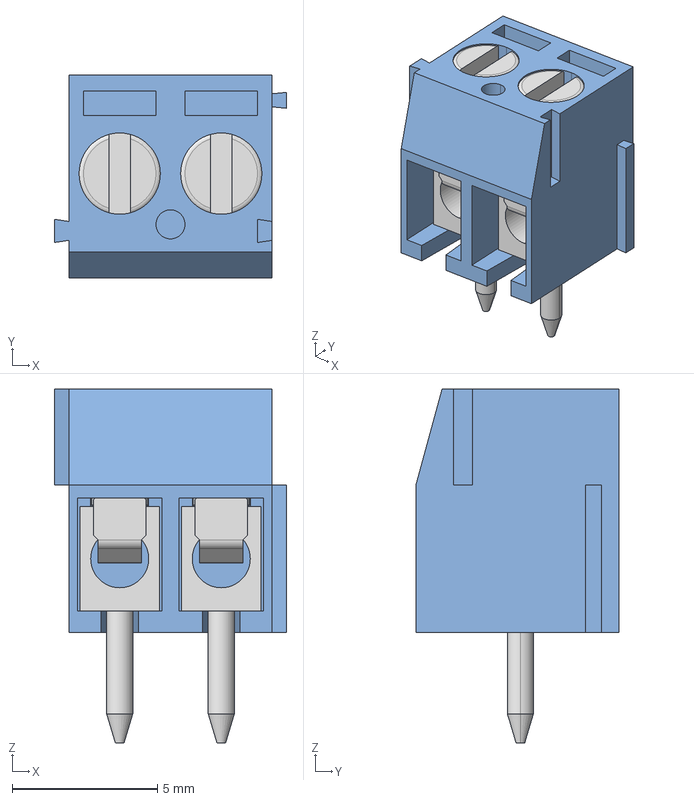
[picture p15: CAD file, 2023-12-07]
kicad_workspace/3d_models/ark_conn.step
8.00 x 7.00 x 12.2 mm

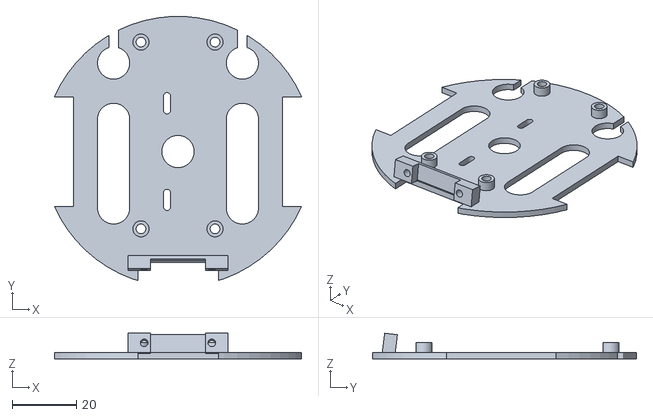
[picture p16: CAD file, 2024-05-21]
cad_models/rpi_board.stl
76.8 x 82.0 x 7.96

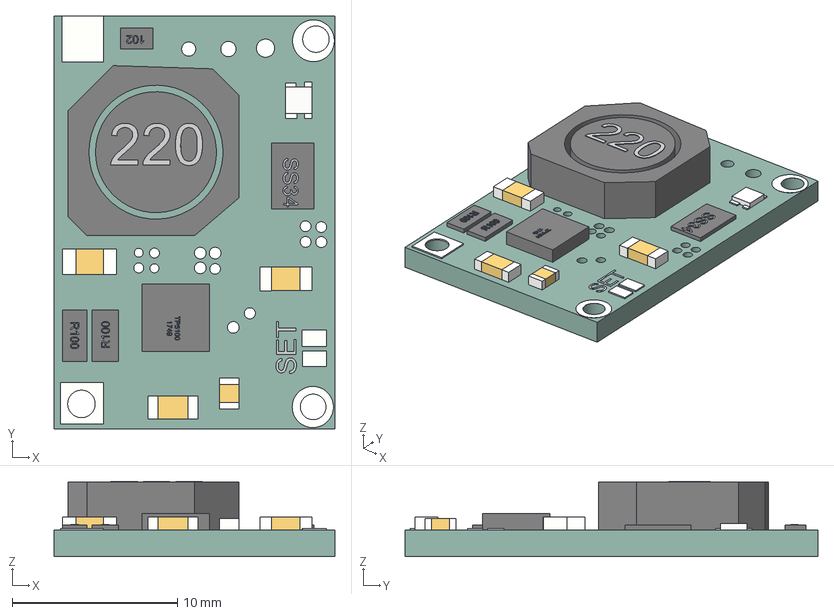
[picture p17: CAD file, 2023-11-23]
kicad_workspace/3d_models/tp5100.step
17.0 x 25.0 x 4.54 mm

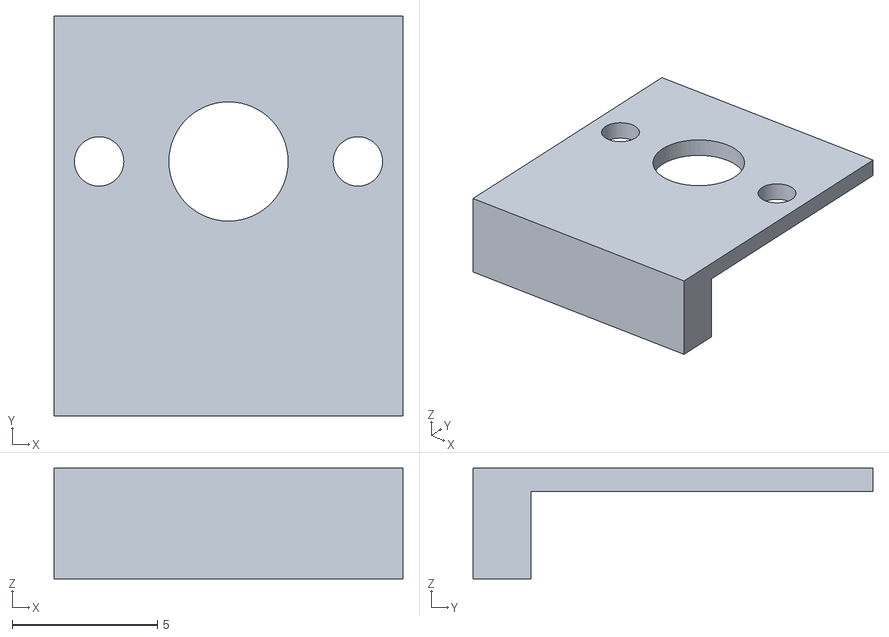
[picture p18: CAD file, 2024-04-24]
cad_models/motor_bracket.stl
12.0 x 13.8 x 3.80

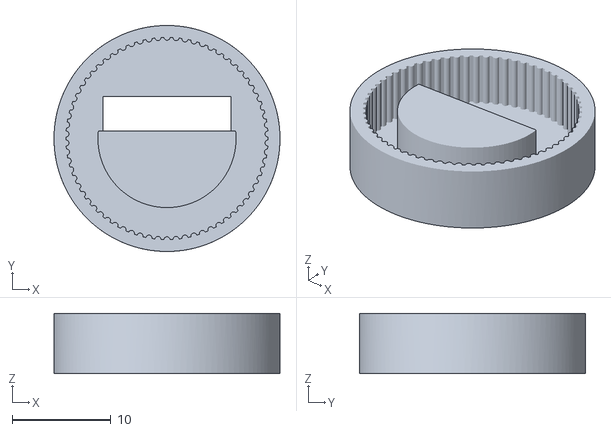
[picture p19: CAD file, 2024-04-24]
cad_models/led_base.stl
22.9 x 22.9 x 6.10

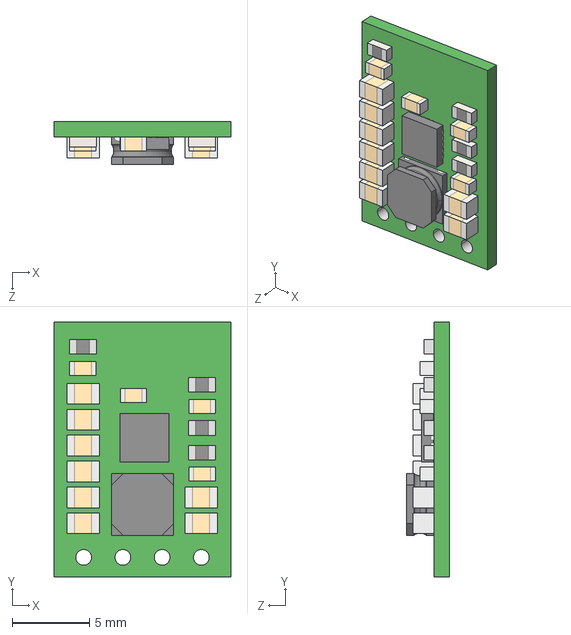
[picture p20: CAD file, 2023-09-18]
kicad_workspace/3d_models/pololu-step-up-step-down-voltage-regulator-s7v8fx.step
11.4 x 16.5 x 2.82 mm

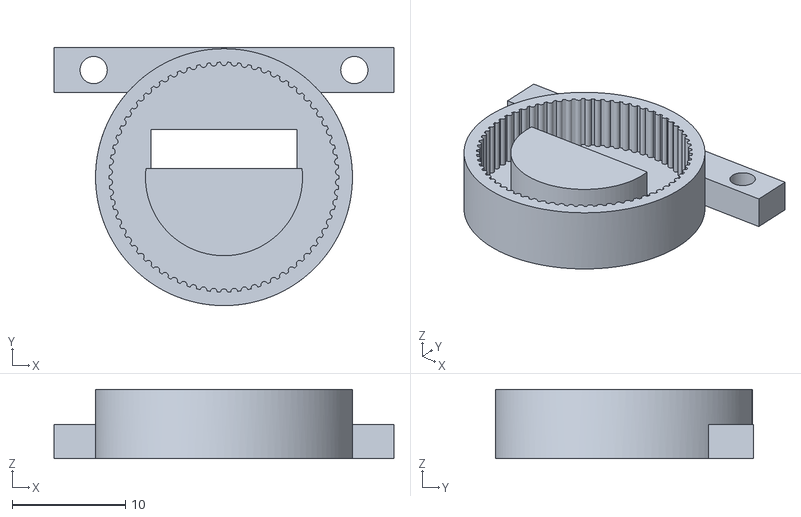
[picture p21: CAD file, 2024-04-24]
cad_models/led.stl
30.0 x 22.8 x 6.10

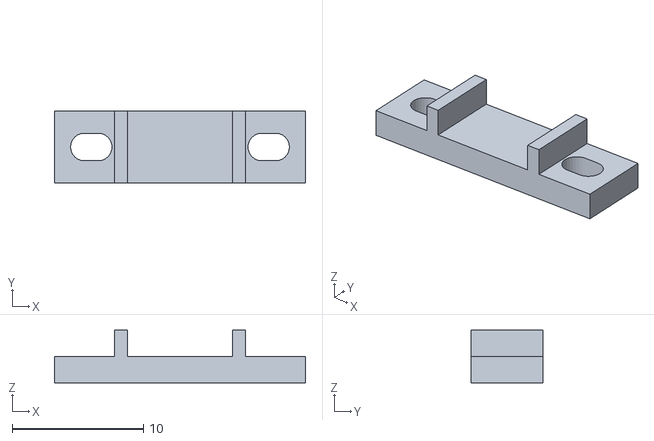
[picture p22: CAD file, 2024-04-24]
cad_models/switch_holder.stl
19.1 x 5.50 x 4.00

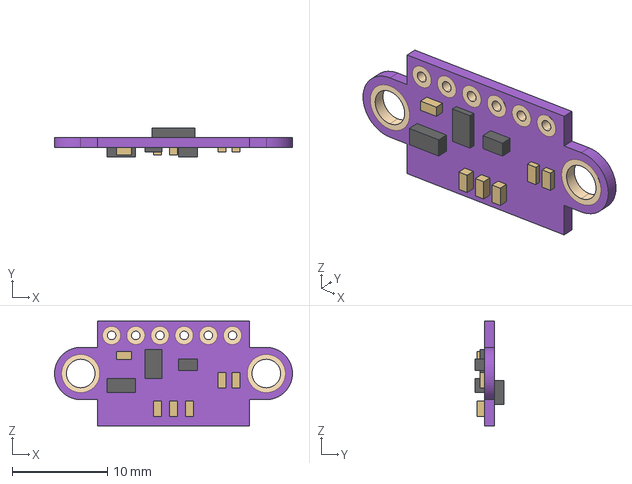
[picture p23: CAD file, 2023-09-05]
kicad_workspace/3d_models/vl53l0x.stp
25.0 x 3.00 x 11.0 mm

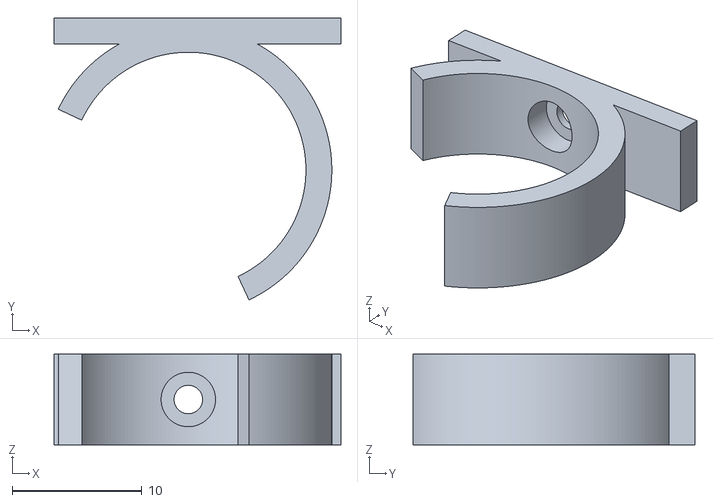
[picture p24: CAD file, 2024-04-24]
cad_models/battery.stl
22.1 x 21.8 x 7.00

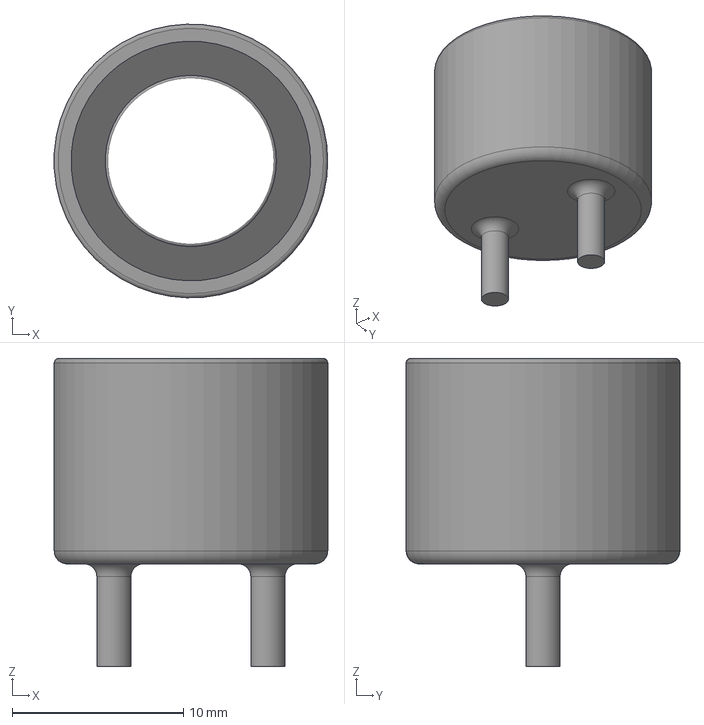
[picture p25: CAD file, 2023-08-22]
kicad_workspace/3d_models/ultrasound.step
16.0 x 16.0 x 18.0 mm

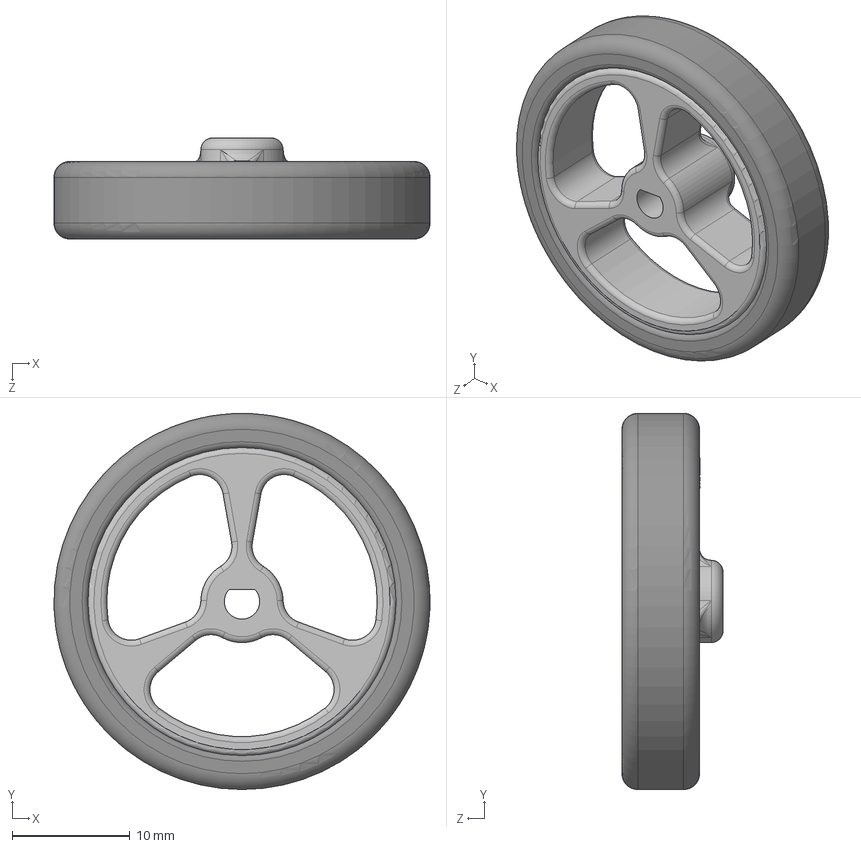
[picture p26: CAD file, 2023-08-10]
kicad_workspace/3d_models/pololu-wheel-32x7mm-black.step
32.0 x 32.0 x 8.60 mm

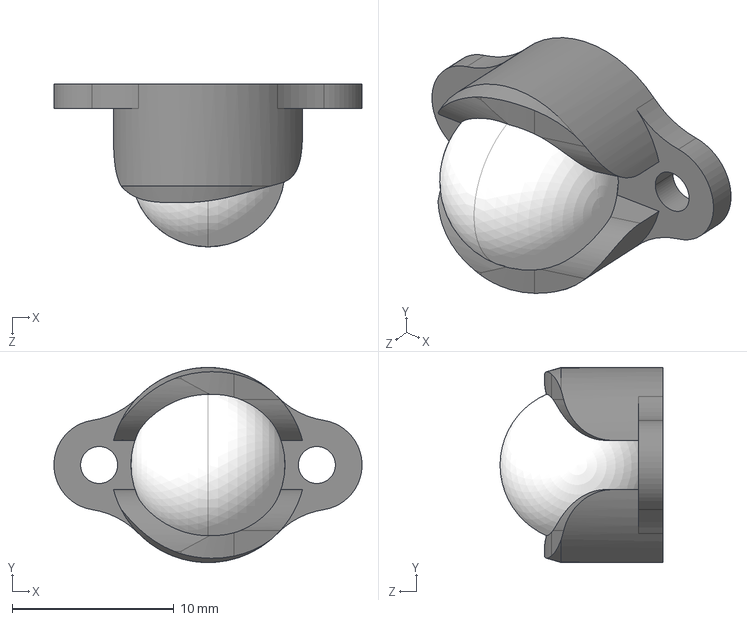
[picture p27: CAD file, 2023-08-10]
kicad_workspace/3d_models/pololu-ball-caster-with-0-375in-ball.step
19.0 x 12.1 x 10.1 mm

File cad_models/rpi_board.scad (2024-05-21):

module pcb() {
	import("../kicad_workspace/bottom/pcb_shape/shape.dxf");
}

module spacer() {
	linear_extrude(height=3) difference() {
		circle(d=5);
		circle(d=3);
	}
}

holes = [
	[3.5,3.5],
	[3.5,3.5+23],
	[65-3.5,3.5],
	[65-3.5,3.5+23]
];

$fn = 60;
h = 2;

camera_holes = [
	[2.0,2.0],
	[25-2.0,2.0],
	[2.0,14.5],
	[25-2.0,14.5]
];

module my_circle(d) {
	hull() {
		translate([0,-d]) circle(d=d);
		translate([0,d]) circle(d=d);
	}
}

camera_x = 25;
camera_y = 23.862;

d = 84;
linear_extrude(height=h) difference() {
	pcb();
	rotate([0,0,90])
		translate([-65/2+5,-30/2])
			for( h = holes ) translate(h) circle(d=3);
				

	#translate([0,-d/2+5/2,0]) square([camera_x, 5], center=true);
	#translate([0,-d/2+5/2,0]) square([camera_x, 10], center=true);
			
	translate([-3.4,15]) my_circle(d=2.2);
	translate([-3.4,-15]) my_circle(d=2.2);

	hull() {
		translate([20,10]) circle(d=10);
		translate([20,-17.5]) circle(d=10);
	}
	
	hull() {
		translate([-20,10]) circle(d=10);
		translate([-20,-17.5]) circle(d=10);
	}
    
    translate([-20,27.5]) circle(d=10);
    translate([20,27.5]) circle(d=10);
    
    translate([20,35]) square([3,10], center=true);
	translate([-20,35]) square([3,10], center=true);
    
	circle(d=10);
}

rotate([0,0,90]) translate([-65/2+5,-30/2,h]) for( hole = holes ) translate(hole) spacer();

translate([0,0,h]) difference() {
    rotation = -7;
    
	translate([-camera_x/2 -3,-d/2+5]) rotate([rotation,0,0]) cube([camera_x+2*3,4,6]);
	
	#translate([-17/2,-d/2+5 - 0.01]) rotate([rotation,0,0]) cube([17,3,6 + 0.01]);
	#translate([25/2-2,-d/2+5, 3]) rotate([-90+rotation,0]) cylinder(d=2.4,h=5);
	#translate([-25/2+2,-d/2+5, 3]) rotate([-90+rotation,0]) cylinder(d=2.4,h=5);
}

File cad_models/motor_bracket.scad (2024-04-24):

x = 12.0;
y = 10.0;

$fn = 60;

hole = [x/2, y/2];

m_holes = [ [1.55,y/2], [12-1.55,y/2] ];
m_hole_d = 1.6 + 0.1;

hole_h = 0.7 + 0.1;
hole_d = 4.1;

pcb_h = 1.75;
//pcb_h = 1.56;

base_th = 2;

linear_extrude(height=hole_h) difference() {
	square([x,y]);
	translate(hole) circle(d=hole_d);
	
	for(m = m_holes) translate(m) circle(d=m_hole_d);
}

linear_extrude(height=hole_h) {
	translate([0,-pcb_h]) square([ x, pcb_h ]);
}

l = 3;
translate([0,0,-l]) 
	#linear_extrude(height=l + hole_h) {
		translate([0,-pcb_h-base_th]) square([x, base_th]);
	}

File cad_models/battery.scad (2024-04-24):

d = 18.15;
th = 2;
h = 7;
r=d/2-th;

$fn = 90*2;

difference() {
	rotate([0,0,-45]) {
		translate([-r,r+th/2,h/2]) rotate([0,0,45])
			translate([0,1,0]) cube([d+2*th, th+2, h], center=true);
		rotate([0,0,-20]) rotate_extrude(angle=220) translate([d/2,0]) square([th,h]);
	}
	
	translate([0,0,h/2]) rotate([-90,0]) cylinder(d=4.2, h=d/2 + 2);
	#translate([0,0,h/2]) rotate([-90,0]) cylinder(d=2.2, h=d);
}

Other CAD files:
kicad_workspace/bottom/pcb_shape/shape_with_mount_holes.FCStd
kicad_workspace/bottom/pcb_shape/shape.FCStd
kicad_workspace/3d_models/magnetic-encoder-pair-kit-for-micro-metal-gearmotors-hpcb-compatible-w1r02a.step
kicad_workspace/3d_models/magnetic-encoder-pair-kit-for-micro-metal-gearmotors-hpcb-compatible-enc03b.step
cad_models/charger.scad
cad_models/led.scad
cad_models/switch_holder.scad
kicad_workspace/3d_models/BQ24250RGER.stp
kicad_workspace/3d_models/INR18650-35E-Samsung.STEP
kicad_workspace/bottom/pcb_shape/shape.dxf

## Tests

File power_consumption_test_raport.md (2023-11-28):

part | voltage | current | notes
-- | -- | -- | -- 
ws2812b x8 | 5V | 0.092A | R (255)
ws2812b x8 | 5V | 0.046A | R (127)
ws2818b x8 | 5V | 0.092A | G (255)
ws2812b x8 | 5V | 0.046A | G (127)
ws2818b x8 | 5V | 0.092A | B (255)
ws2818b x8 | 5V | 0.046A | B (127)
ws2818b x8 | 5V | 0.183A | RG (255)
ws2818b x8 | 5V | 0.183A | RB (255)
ws2818b x8 | 5V | 0.184A | GB (255)
ws2818b x8 | 5V | 0.273A | RGB (255)
ws2818b x8 | 5V | 0.136A | RGB (127)
ws2818b x8 | 5V | 0.068A | RGB (63) (too bright to look at)
ws2818b x8 | 5V | 0.034A | RGB (31) (clearly visible from distance)
ws2818b x8 | 5V | 0.016A | RGB (15) (might be too dim, depends on external light)
| | | | |
n20 motor | 5V | 0.140A +- 0.020A | free running
n20 motor | 5V | 0.370A +- 0.050A | trying a bit to stall with hand
n20 motor | 5V | 0.800A +- 0.100A | trying to stall hard
| | | | |
Rpi Zero 2 W + Camera v3 | 5V | 0.121A | Legacy 64bit Lite Raspbian + idle + connected SSH
Rpi Zero 2 W + Camera v3 | 5V | 0.279A +- 0.020A | Legacy 64bit Lite Raspbian + stream camera video over tcp
Rpi Zero 2 W + Camera v3 | 5V | 0.412A +- 0.020A | Legacy 64bit Lite Raspbian + stream camera vide over tcp + load core with python3 sum loop
Rpi Zero 2 W + Camera v3 | 5V | 0.656A +- 0.020A | Legacy 64bit Lite Raspbian + load all 4 cores
Rpi Zero 2 W + Camera v3 | 5V | peak: 0.857A, typical: 0.450A - 0.650A | Legacy 64bit Raspbian (+desktop) + openCV ArUco detection
Rpi Zero 2 W + Camera v3 | 5V | 0.050A | shutdown
| | | | |
VL53L0X | 3.3V | 0.021A | high accuracy mode (25ms between readings)
VL53L0X | 3.3V | 0.018A | continous mode (25ms between readings)
VL53L0X | 3.3V | 0.005A | high speed mode (25ms between readings)
| | | | |
NUCLEO L152RE dev board | 5V | 0.058A | whole nucleo with 10Hz blink program on HAL
| | | | |
Motor encoder | 3.3V | 0.003A | -
| | | | |
U3V70A | 3.0V | 0.00056A | standby step up current
U3V70A | 3.3V | 0.0005A | standby step up current
U3V70A | 3.7V | 0.00045A | standby step up current
U3V70A | 4.2V | 0.00039A | standby step up current
| | | | |
RPI + 2 motors + WS2812B | 3V (on step up) | 2.6A - 2.8A  (to step up) | RPI all cores stressed, WS2812B RGB 127, 2 motors constantly spinnig with rapid direction change
| | | | |
TP5100 | 8V | 1.82A | board #1, current to battery
TP5100 | 8V | 1.87A | board #2, current to battery
TP5100 | 8V | 1.90A | board #3, current to battery
| | | | |
S7V8F3 | 2.8V | 0.41A | input U, output I, a little warmer than room temperature
S7V8F3 | 4.2V | 0.41A | input U, output I, a little warmer than room temperature
S7V8F3 | 4.2V | 0.80A | input U, output I, warm to touch, but within acceptable range
S7V8F3 | 3.3V | 0.80A | input U, output I, warm
S7V8F3 | 2.8V | 0.80A | input U, output I, extremly hot

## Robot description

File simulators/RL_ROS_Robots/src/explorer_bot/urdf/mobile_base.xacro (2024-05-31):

<?xml version="1.0"?>
<robot xmlns:xacro="http://www.ros.org/wiki/xacro">

    <xacro:property name="base_diameter" value="0.4" />
    <xacro:property name="base_length" value="0.14" /> <!-- Length - wysokosc podstawy -->
    <xacro:property name="wheel_radius" value="0.1" />
    <xacro:property name="wheel_length" value="0.05" />
    <xacro:property name="turret_radius" value="0.05" />
    <xacro:property name="turret_length" value="0.2" />

    
    <link name="base_footprint" />

    <link name="base_link">
        <visual>
            <geometry>
                <cylinder radius="${base_diameter / 2.0}" length="${base_length}"/>
            </geometry>
            <origin xyz="0 0 ${base_length / 2.0}" rpy="0 0 0" />
            <material name="black" />
        </visual>
        <collision>
            <geometry>
                <cylinder radius="${base_diameter / 2.0}" length="${base_length}"/>
            </geometry>
            <origin xyz="0 0 ${base_length / 2.0}" rpy="0 0 0" />    
        </collision>
        <xacro:cylinder_inertia m="5.0" r="${2*base_diameter / 2.0}" h="${2*base_length}" xyz="0 0 ${base_length / 2.0}" rpy="0 0 0" />        
    </link>

    <link name="turret_link">
        <visual>
            <geometry>
                <cylinder radius="${turret_radius}" length="${turret_length}"/>
            </geometry>
            <origin xyz="0 0 0.1" rpy="0 0 0"/>
            <material name="white"/>
        </visual>
        <collision>
            <geometry>
                <cylinder radius="${turret_radius}" length="${turret_length}"/>
            </geometry>
            <origin xyz="0 0 0.1" rpy="0 0 0"/>        
        </collision>
        <xacro:cylinder_inertia m="1.0" r="${turret_radius}" h="${turret_length}" xyz="0 0 0.1" rpy="0 0 0" />            
    </link>

    <link name="turret_top_link">
        <visual>
            <geometry>
                <cylinder radius="${turret_radius + 0.01}" length="${turret_radius}"/> 
            </geometry>
            <origin xyz="0 0 0.05" rpy="0 0 0"/> 
            <material name="black"/>
        </visual>
        <collision>
            <geometry>
                <cylinder radius="${turret_radius + 0.01}" length="${turret_radius}"/> 
            </geometry>
            <origin xyz="0 0 0.05" rpy="0 0 0"/>         
        </collision>        
        <xacro:cylinder_inertia m="0.2" r="${turret_radius + 0.01}" h="${turret_radius}" xyz="0 0 0.05" rpy="0 0 0" />        
    </link>

    <xacro:macro name="wheel_link" params="prefix">
        <link name="${prefix}_wheel_link">
            <visual>
                <geometry>
                    <cylinder radius="${wheel_radius}" length="${wheel_length}" />
                </geometry>
                <origin xyz="0 0 0" rpy="${pi / 2.0} 0 0" />
                <material name="grey" />
            </visual>
            <collision>
                <geometry>
                    <cylinder radius="${wheel_radius}" length="${wheel_length}" />
                </geometry>
                <origin xyz="0 0 0" rpy="${pi / 2.0} 0 0" />    
            </collision>            
            <xacro:cylinder_inertia m="2.0" r="${2*wheel_radius}" h="${2*wheel_length}" xyz="0 0 0" rpy="${pi / 2.0} 0 0" />        
        </link>           
    </xacro:macro>

    <xacro:wheel_link prefix="right" />
    <xacro:wheel_link prefix="left" />


    <link name="caster_wheel_link">
        <visual>
            <geometry>
                <sphere radius="${(wheel_radius) / 2.0}" />
            </geometry>
            <origin xyz="0 0 0" rpy="0 0 0" />
            <material name="grey" />
        </visual>
        <collision>
            <geometry>
                <sphere radius="${(wheel_radius + 0.02) / 2.0}" />
            </geometry>
            <origin xyz="0 0 0" rpy="0 0 0" />        
        </collision>
        <xacro:sphere_inertia m="8.0" r="${2*(wheel_radius + 0.02) / 2.0}" xyz="0 0 0" rpy="0 0 0" />
    </link>

    <joint name="base_joint" type="fixed">
        <parent link="base_footprint" />
        <child link="base_link" />
        <origin xyz="0 0 ${wheel_radius}" rpy="0 0 0"/>
    </joint>

    <joint name="base_turret_joint" type="fixed">
        <parent link="base_link"/>
        <child link="turret_link"/>
        <origin xyz="0 0 ${base_length}" rpy="0 0 0"/>
    </joint>

    <joint name="turret_top_joint" type="fixed">
        <parent link="turret_link"/>
        <child link="turret_top_link"/>
        <origin xyz="0 0 0.175" rpy="0 0 0"/>
    </joint>

    <joint name="base_right_wheel_joint" type="continuous">
        <parent link="base_link" />
        <child link="right_wheel_link" />
        <origin xyz="0 ${-(base_diameter + wheel_length) / 2.0} 0" rpy="0 0 0" />
        <axis xyz="0 1 0" />
    </joint>

    <joint name="base_left_wheel_joint" type="continuous">
        <parent link="base_link" />
        <child link="left_wheel_link" />
        <origin xyz="0 ${(base_diameter + wheel_length) / 2.0} 0" rpy="0 0 0" />
        <axis xyz="0 1 0" />
    </joint>

    <joint name="base_caster_wheel_joint" type="fixed">
        <parent link="base_link" />
        <child link="caster_wheel_link" />
        <origin xyz="${base_diameter / 3.0} 0 ${-wheel_radius / 2.0}" rpy="0 0 0" />
    </joint>


</robot>

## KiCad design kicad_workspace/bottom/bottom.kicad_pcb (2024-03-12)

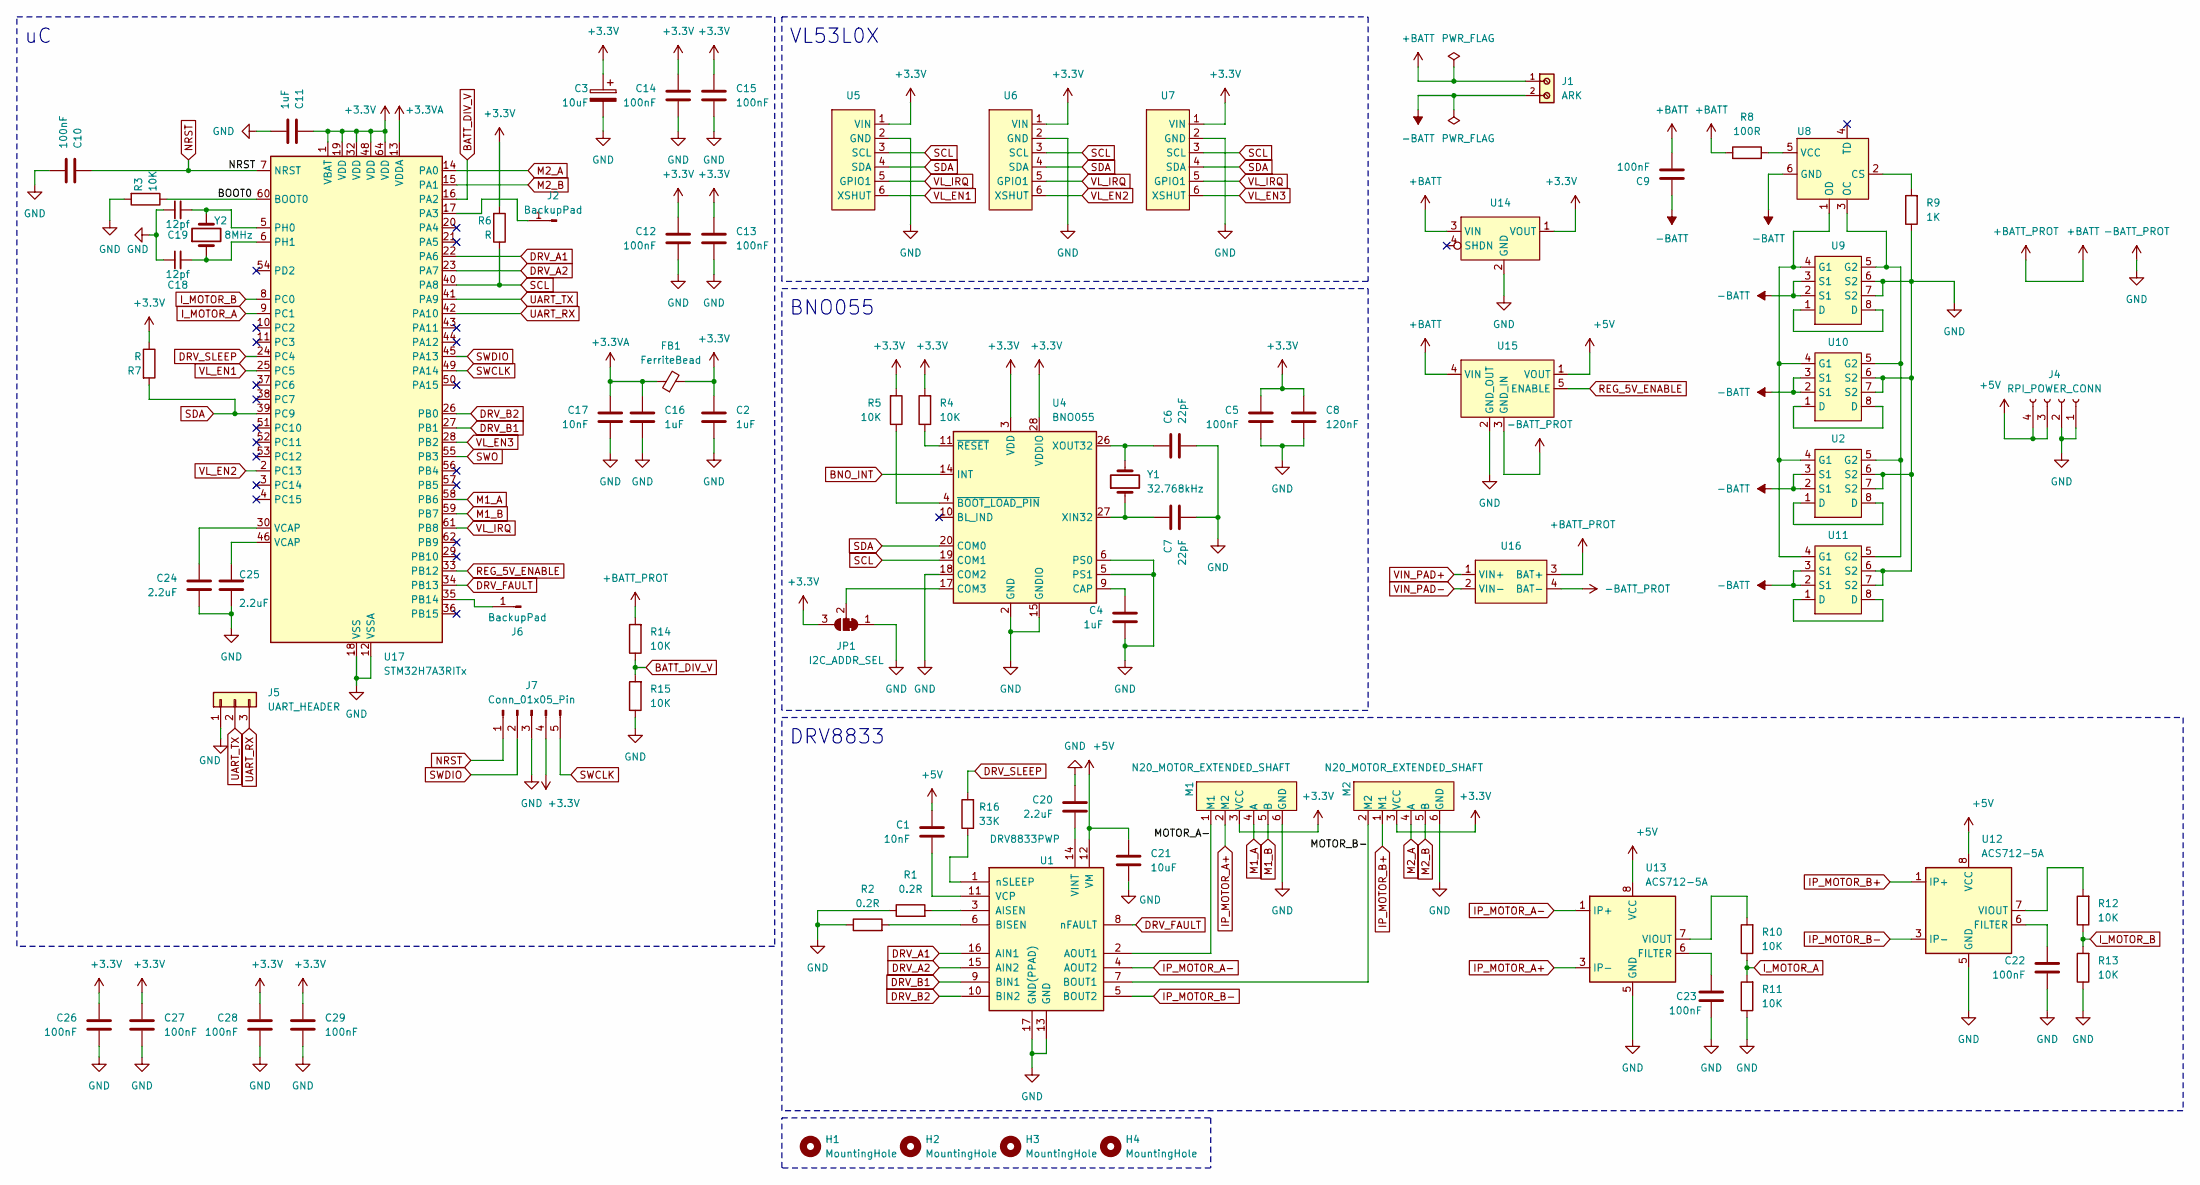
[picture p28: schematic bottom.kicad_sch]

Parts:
C1, C17: 10nF; C_0805_2012Metric
C2, C4, C11, C16: 1uF; C_0805_2012Metric
C3: 10uF; CP_Elec_4x3
C5, C9, C10, C12, C13, C14, C15, C22, C23, C26, C27, C28, C29: 100nF; C_0805_2012Metric
C6, C7: 22pF; C_0805_2012Metric
C8: 120nF; C_0805_2012Metric
C18, C19: 12pf; C_0805_2012Metric
C20, C24, C25: 2.2uF; C_0805_2012Metric
C21: 10uF; C_0805_2012Metric
FB1: FerriteBead; L_0805_2012Metric
H1, H2, H3, H4: MountingHole
J1: ARK; 691103110002; PART-NUMBER 691103110002
J2, J6: BackupPad; SolderWirePad_1x01_SMD_1x2mm
J4: RPI_POWER_CONN; JST_XH_B4B-XH-A_1x04_P2.50mm_Vertical
J5: UART_HEADER; PinHeader_1x03_P2.54mm_Vertical
J7: Conn_01x05_Pin; Harwin_M20-89005xx_1x05_P2.54mm_Horizontal
JP1: I2C_ADDR_SEL; SolderJumper-3_P1.3mm_Bridged12_Pad1.0x1.5mm_NumberLabels
M1, M2: N20_MOTOR_EXTENDED_SHAFT; N20_EXTENDED_SHAFT
R1, R2: 0.2R; R_0805_2012Metric
R3, R4, R5, R10, R11, R12, R13, R14, R15: 10K; R_0805_2012Metric
R6, R7: R; R_0805_2012Metric
R8: 100R; R_0805_2012Metric
R9: 1K; R_0805_2012Metric
R16: 33K; R_0805_2012Metric
U1: DRV8833PWP; TSSOP-16-1EP_4.4x5mm_P0.65mm_EP3x3mm_ThermalVias
U2, U9, U10, U11: TSSOP-8_4.4x3mm_P0.65mm
U4: BNO055; LGA-28_5.2x3.8mm_P0.5mm
U5, U6, U7: VL53L0X
U8: SOT-23-6
U12, U13: ACS712-5A; SOIC-8_3.9x4.9mm_P1.27mm
U14: S7V8F3_vertical
U15: U3V70F5
U16: TP5100
U17: STM32H7A3RITx; LQFP-64_10x10mm_P0.5mm
Y1: 32.768kHz; Crystal_SMD_MicroCrystal_CM9V-T1A-2Pin_1.6x1.0mm
Y2: 8MHz; Crystal_SMD_MicroCrystal_CM9V-T1A-2Pin_1.6x1.0mm

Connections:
+3.3V: C2.1, C3.1, C5.1, C8.1, C11.1, C12.1, C13.1, C14.1, C15.1, C26.1, C27.1, C28.1, C29.1, FB1.2, J7.4, JP1.3 (B), M1.3 (VCC), M2.3 (VCC), R4.2, R5.2, R6.2, R7.1, U4.3 (VDD), U4.28 (VDDIO), U5.1 (VIN), U6.1 (VIN), U7.1 (VIN), U14.1 (VOUT), U17.1 (VBAT), U17.19 (VDD), U17.32 (VDD), U17.48 (VDD), U17.64 (VDD)
+3.3VA: C16.1, C17.1, FB1.1, U17.13 (VDDA)
+5V: C1.1, C21.1, J4.3, J4.4, U1.12 (VM), U12.8 (VCC), U13.8 (VCC), U15.1 (VOUT)
+BATT: C9.2, J1.1, R8.1, R14.2, U14.3 (VIN), U15.4 (VIN), U16.3 (BAT+)
-BATT: C9.1, J1.2, U2.2 (S1), U2.3 (S1), U8.6 (GND), U9.2 (S1), U9.3 (S1), U10.2 (S1), U10.3 (S1), U11.2 (S1), U11.3 (S1)
-BATT_PROT: C2.2, C3.2, C4.2, C5.2, C6.2, C7.2, C8.2, C10.2, C11.2, C12.2, C13.2, C14.2, C15.2, C16.2, C17.2, C18.1, C19.1, C20.1, C21.2, C22.2, C23.2, C24.2, C25.2, C26.2, C27.2, C28.2, C29.2, J4.1, J4.2, J5.1, J7.3, JP1.1 (A), M1.6 (GND), M2.6 (GND), R1.1, R2.1, R3.2, R9.1, R11.1, R13.1, R15.1, U1.13 (GND), U1.17 (GND(PPAD)), U2.6 (S2), U2.7 (S2), U4.2 (GND), U4.5 (PS1), U4.6 (PS0), U4.15 (GNDIO), U4.16 (GNDIO), U4.18 (COM2), U4.25 (GNDIO), U5.2 (GND), U6.2 (GND), U7.2 (GND), U9.6 (S2), U9.7 (S2), U10.6 (S2), U10.7 (S2), U11.6 (S2), U11.7 (S2), U12.5 (GND), U13.5 (GND), U14.2 (GND), U15.2 (GND_OUT), U15.3 (GND_IN), U16.4 (BAT-), U17.12 (VSSA), U17.18 (VSS), U17.31 (VSS), U17.47 (VSS), U17.63 (VSS)
/BOOT0: R3.1, U17.60 (BOOT0)
/MOTOR_A-: M1.1 (M1), U1.2 (AOUT1)
BATT_DIV_V: R14.1, R15.2, U17.16 (PA2)
BNO_INT: U4.14 (INT)
DRV_A1: U1.16 (AIN1), U17.22 (PA6)
DRV_A2: U1.15 (AIN2), U17.23 (PA7)
DRV_B1: U1.9 (BIN1), U17.27 (PB1)
DRV_B2: U1.10 (BIN2), U17.26 (PB0)
DRV_FAULT: U1.8 (nFAULT), U17.34 (PB13)
DRV_SLEEP: R16.2, U17.24 (PC4)
IP_MOTOR_A+: M1.2 (M2), U13.3 (IP-), U13.4 (IP-)
IP_MOTOR_A-: U1.4 (AOUT2), U13.1 (IP+), U13.2 (IP+)
IP_MOTOR_B-: U1.5 (BOUT2), U12.3 (IP-), U12.4 (IP-)
I_MOTOR_A: R10.1, R11.2, U17.9 (PC1)
I_MOTOR_B: R12.1, R13.2, U17.8 (PC0)
M1_A: M1.4 (A), U17.58 (PB6)
M1_B: M1.5 (B), U17.59 (PB7)
M2_A: M2.4 (A), U17.14 (PA0)
M2_B: M2.5 (B), U17.15 (PA1)
NRST: C10.1, J7.1, U17.7 (NRST)
unnamed: C24.1, U17.30 (VCAP)
unnamed: C25.1, U17.46 (VCAP)
unnamed: J2.1, U17.17 (PA3)
unnamed: J6.1, U17.35 (PB14)
unnamed: JP1.2 (C), U4.17 (COM3)
unnamed: R1.2, U1.3 (AISEN)
unnamed: R2.2, U1.6 (BISEN)
unnamed: C1.2, U1.11 (VCP)
unnamed: C20.2, U1.14 (VINT)
unnamed: R16.1, U1.1 (nSLEEP)
unnamed: U2.1 (D), U2.8 (D)
unnamed: C4.1, U4.9 (CAP)
unnamed: C7.1, U4.27 (XIN32), Y1.1
unnamed: C6.1, U4.26 (XOUT32), Y1.2
unnamed: R5.1, U4.4 (~BOOT_LOAD_PIN)
unnamed: R4.1, U4.11 (~RESET)
unnamed: R9.2, U8.2 (CS)
unnamed: R8.2, U8.5 (VCC)
unnamed: U9.1 (D), U9.8 (D)
unnamed: U10.1 (D), U10.8 (D)
unnamed: U2.4 (G1), U8.1 (OD), U9.4 (G1), U10.4 (G1), U11.4 (G1)
unnamed: U2.5 (G2), U8.3 (OC), U9.5 (G2), U10.5 (G2), U11.5 (G2)
unnamed: U11.1 (D), U11.8 (D)
unnamed: C22.1, U12.6 (FILTER)
unnamed: R12.2, U12.7 (VIOUT)
unnamed: C23.1, U13.6 (FILTER)
unnamed: R10.2, U13.7 (VIOUT)
unnamed: C19.2, U17.5 (PH0), Y2.2
unnamed: C18.2, U17.6 (PH1), Y2.1
REG_5V_ENABLE: U15.5 (ENABLE), U17.33 (PB12)
SCL: R6.1, U4.19 (COM1), U5.3 (SCL), U6.3 (SCL), U7.3 (SCL), U17.40 (PA8)
SDA: R7.2, U4.20 (COM0), U5.4 (SDA), U6.4 (SDA), U7.4 (SDA), U17.39 (PC9)
SWCLK: J7.5, U17.49 (PA14)
SWDIO: J7.2, U17.45 (PA13)
SWO: U17.55 (PB3)
UART_RX: J5.3, U17.42 (PA10)
UART_TX: J5.2, U17.41 (PA9)
VIN_PAD+: U16.1 (VIN+)
VIN_PAD-: U16.2 (VIN-)
VL_EN1: U5.6 (XSHUT), U17.25 (PC5)
VL_EN2: U6.6 (XSHUT), U17.2 (PC13)
VL_EN3: U7.6 (XSHUT), U17.28 (PB2)
VL_IRQ: U5.5 (GPIO1), U6.5 (GPIO1), U7.5 (GPIO1), U17.61 (PB8)

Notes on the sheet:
DRV8833
VL53L0X
BNO055

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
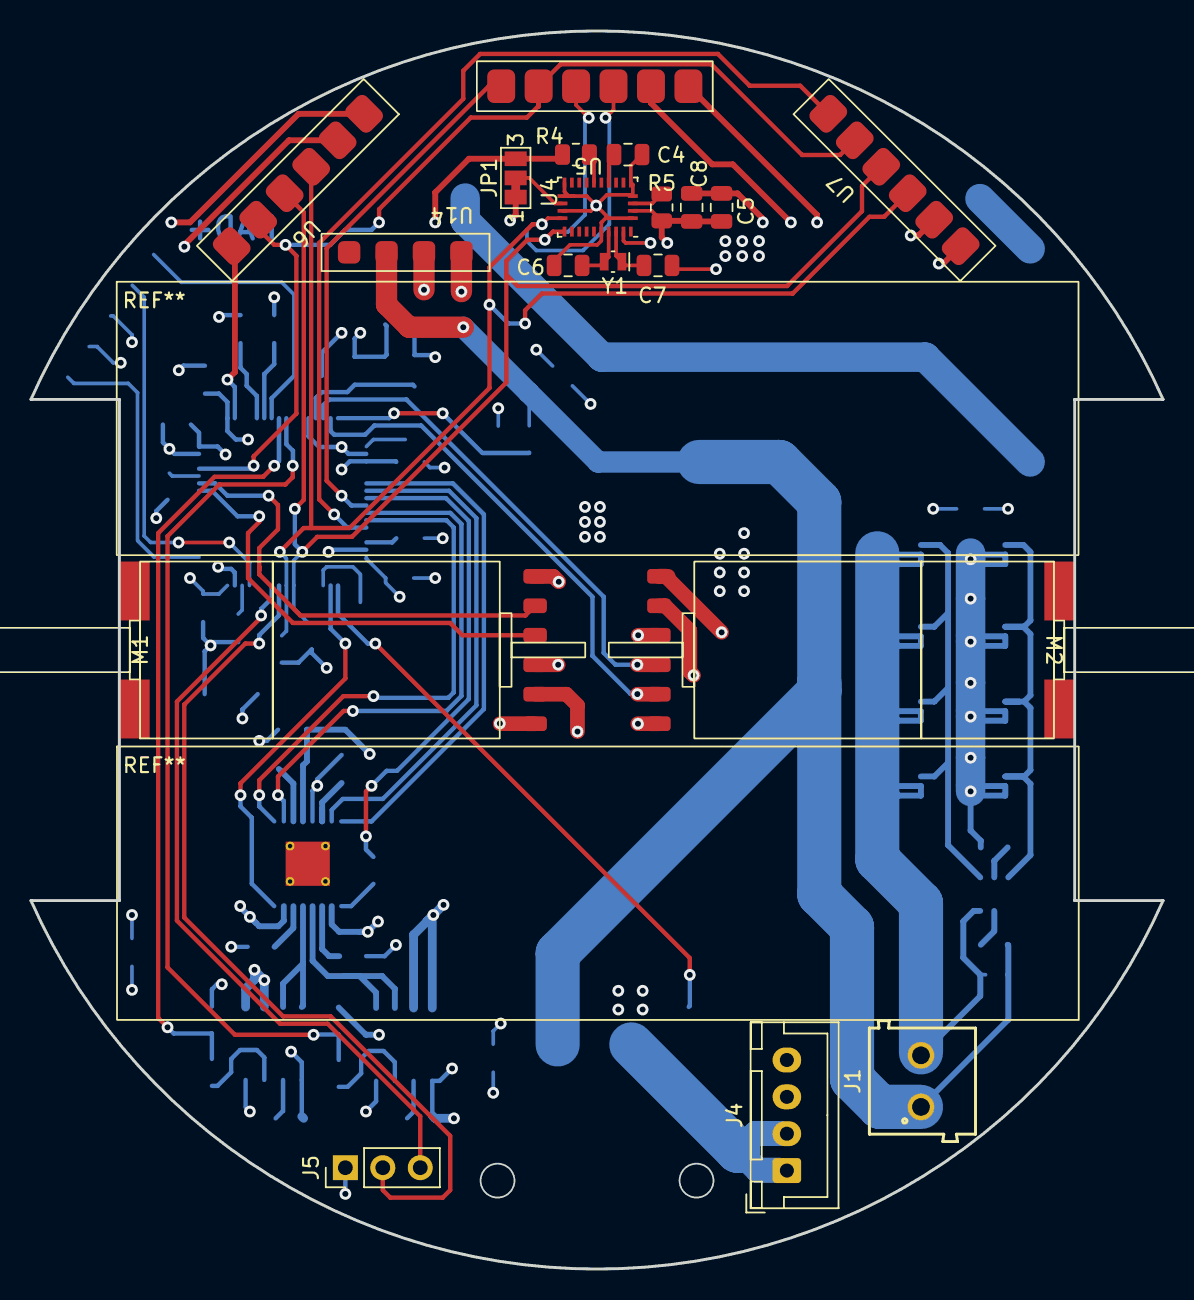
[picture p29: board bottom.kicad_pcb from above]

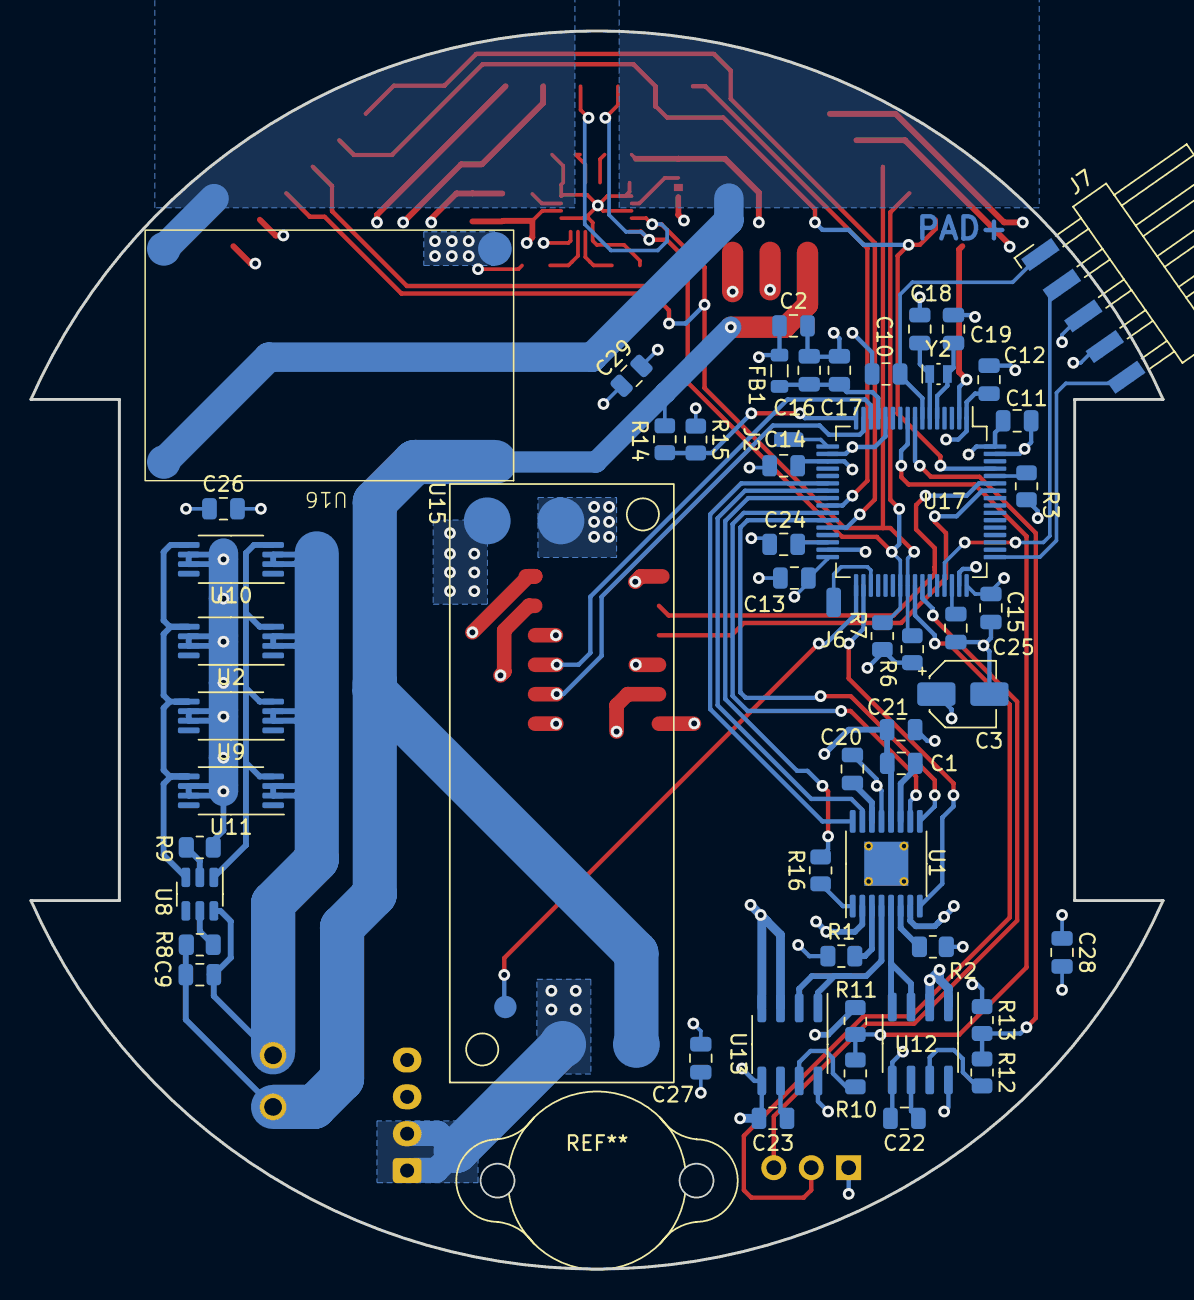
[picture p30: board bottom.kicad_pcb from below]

Board: 4 copper layers, 76.8 x 84.0 mm, 73 parts (54 on the bottom side), 67 nets.

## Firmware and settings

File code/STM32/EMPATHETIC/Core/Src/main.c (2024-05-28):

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
/* Includes ------------------------------------------------------------------*/
#include "main.h"
#include "i2c.h"
#include "usart.h"
#include "tim.h"
#include "gpio.h"

/* USER CODE BEGIN Includes */
#include <stdio.h>
#include <stdlib.h>

#include "drv8833.h"
#include "enc_inc.h"
#include "enc_A_LPF_biquad_df1.h"
#include "enc_B_LPF_biquad_df1.h"
#include "pid_controller.h"

#include "vl.h"
/* USER CODE END Includes */

/* USER CODE BEGIN PD */
#define TIME_BETWEEN_MEASUREMENTS 200		// Time between VL measurements
//#define HEARTBEAT_ENABLE
#define EMERGENCY_STOP_DISTANCE 50
/* USER CODE END PD */


/* USER CODE BEGIN PV */
DRV8833_TypeDef hdrv8833 = {
		.AIN_1 = PWM_INIT_HANDLE(&htim3, TIM_CHANNEL_1), .AIN_2 =
		PWM_INIT_HANDLE(&htim3, TIM_CHANNEL_2), .BIN_1 =
		PWM_INIT_HANDLE(&htim3, TIM_CHANNEL_3), .BIN_2 =
		PWM_INIT_HANDLE(&htim3, TIM_CHANNEL_4) };

float duty_A = 0;
float duty_B = 0;

ENC_INC_Handle_TypeDef henc_A = {
		.Encoder = &htim4, .Channel = TIM_CHANNEL_ALL, .Counter = 0,
		.CounterPrev = 0, .CounterDiff = 0, .Ts = 0.01 /* 10 ms */, .ppr = 12 };

float w_A = 0;  // [rad/s]
float wf_A = 0;  // [rad/s]

ENC_INC_Handle_TypeDef henc_B = {
		.Encoder = &htim2, .Channel = TIM_CHANNEL_ALL, .Counter = 0,
		.CounterPrev = 0, .CounterDiff = 0, .Ts = 0.01 /* 10 ms */, .ppr = 12 };

float w_B = 0;  // [rad/s]
float wf_B = 0;  // [rad/s]

PID_HandleTypeDef hpid_A = {
		.Kp = 0.0, .Ki = 0.5, .Kd = 0, .N = 1, .Ts = 0.01, .LimitLower = -100,
		.LimitUpper = 100 };

float w_A_ref = 0;

PID_HandleTypeDef hpid_B = {
		.Kp = 0.0, .Ki = 0.5, .Kd = 0, .N = 1, .Ts = 0.01, .LimitLower = -100,
		.LimitUpper = 100 };

float w_B_ref = 0;

unsigned char RxMsg[32];
unsigned int RxMsgLen = 10;

int print_irq = 0;
int print_rx = 0;
/* USER CODE END PV */

void SystemClock_Config( void );
/* USER CODE BEGIN 0 */
/**
 * @brief  Period elapsed callback in non-blocking mode to handle PID loop for motors
 * @param  htim TIM handle
 * @retval None
 */
void HAL_TIM_PeriodElapsedCallback( TIM_HandleTypeDef * htim ) {
	if( htim == &htim15 ) {
		// Negative encoder value, similar to motors, are caused by random magnet orientation
		w_A = -ENC_INC_Update( &henc_A );
		arm_biquad_cascade_df1_f32(
				&enc_A_LPF, &w_A, &wf_A, ENC_A_LPF_BLOCK_SIZE );
		if( w_A_ref == 0 ) {
			duty_A = 0;
		} else {
			duty_A = PID_GetOutput( &hpid_A, w_A_ref, wf_A );
		}
		drv8833_speed_change( &hdrv8833, A, duty_A );

		w_B = ENC_INC_Update( &henc_B );
		arm_biquad_cascade_df1_f32(
				&enc_B_LPF, &w_B, &wf_B, ENC_B_LPF_BLOCK_SIZE );
		if( w_B_ref == 0 ) {
			duty_B = 0;
		} else {
			duty_B = PID_GetOutput( &hpid_B, w_B_ref, wf_B );
		}
		drv8833_speed_change( &hdrv8833, B, duty_B );
	}
}

/**
 * @brief  Rx Transfer completed callback for receiving motors' speed
 * @param  huart UART handle.
 * @retval None
 */
void HAL_UART_RxCpltCallback( UART_HandleTypeDef * huart ) {
	if( huart != &hlpuart1 )
		return;

	int value_left, value_right;

	// Might be too slow to keep in IRQ
	(void)sscanf( (const char*)RxMsg, "L%dR%d", &value_left, &value_right );

	// Negative value just reverse robot direction due to random motors' polarity when soldering
	w_A_ref = -value_left;
	w_B_ref = -value_right;

	(void)HAL_UART_Receive_IT( &hlpuart1, RxMsg, RxMsgLen );
}

/* USER CODE END 0 */

/**
 * @brief  The application entry point.
 * @retval int
 */
int main( void ) {

	/* MCU Configuration--------------------------------------------------------*/

	/* Reset of all peripherals, Initializes the Flash interface and the Systick. */
	HAL_Init();

	/* Configure the system clock */
	SystemClock_Config();

	/* Initialize all configured peripherals */
	MX_GPIO_Init();
	MX_LPUART1_UART_Init();
	MX_TIM3_Init();
	MX_TIM4_Init();
	MX_TIM2_Init();
	MX_TIM15_Init();
	MX_I2C3_Init();
	/* USER CODE BEGIN 2 */
	drv8833_init( &hdrv8833 );
	drv8833_start( &hdrv8833 );

	PID_Init( &hpid_A );
	arm_biquad_cascade_df1_init_f32(
			&enc_A_LPF, ENC_A_LPF_NUM_STAGES, enc_A_LPF_COEFFS,
			enc_A_LPF_STATE );
	ENC_INC_Init( &henc_A );

	arm_biquad_cascade_df1_init_f32(
			&enc_B_LPF, ENC_B_LPF_NUM_STAGES, enc_B_LPF_COEFFS,
			enc_B_LPF_STATE );
	ENC_INC_Init( &henc_B );

	HAL_TIM_Base_Start_IT( &htim15 );
	HAL_UART_Receive_IT( &hlpuart1, RxMsg, RxMsgLen );

	HAL_UART_Transmit( &hlpuart1, (const uint8_t*)"Started.\r\n", 10,
	HAL_MAX_DELAY );

	vl_init( &hi2c3 );
	/* USER CODE END 2 */

	/* Infinite loop */
	/* USER CODE BEGIN WHILE */
#ifdef HEARTBEAT_ENABLE
	uint32_t heart = HAL_GetTick();
#endif
	uint32_t distance_timer = HAL_GetTick();
	while( 1 ) {
#ifdef HEARTBEAT_ENABLE
		if( heart - HAL_GetTick() > 1000 )
			HAL_UART_Transmit(
					&hlpuart1, (const uint8_t*)". ", 2, HAL_MAX_DELAY );  // Send heartbeat dot
#endif

		// Start distance measurement
		if( HAL_GetTick() - distance_timer > TIME_BETWEEN_MEASUREMENTS ) {
			uint16_t distance;

			// This measurement is blocking for now. It takes approximately 33ms + 2ms = 35ms, so it is fine until it is only task in main loop
			if( vl_get_distance( &distance ) ) {
				uint8_t msg_buf[64];
				uint8_t len = sprintf(
						(char*)msg_buf, "Measured_distance: %i\n\r", distance );
				HAL_UART_Transmit( &hlpuart1, msg_buf, len, HAL_MAX_DELAY );

				// Emergency stop when distance is low
				if( distance < EMERGENCY_STOP_DISTANCE ) {
					w_A_ref = 0;
					w_B_ref = 0;
				}
			}

			distance_timer = HAL_GetTick();
		}

		/* USER CODE END WHILE */

		/* USER CODE BEGIN 3 */
	}
	/* USER CODE END 3 */
}

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


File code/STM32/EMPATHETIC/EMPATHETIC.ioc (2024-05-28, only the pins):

Mcu.UserName=STM32H7A3RITx
PA0.GPIO_Label=Enkoder silnika 2 Hall 1
PA0.Signal=S_TIM2_CH1_ETR
PA1.GPIO_Label=Enkoder silnika 2 Hall 2
PA1.Signal=S_TIM2_CH2
PA10.Signal=LPUART1_RX
PA3.GPIO_Label=DEBUG
PA3.Signal=GPIO_Output
PA6.Signal=S_TIM3_CH1
PA7.Signal=S_TIM3_CH2
PA8.Signal=I2C3_SCL
PA9.Signal=LPUART1_TX
PB0.Signal=S_TIM3_CH3
PB1.Signal=S_TIM3_CH4
PB13.GPIO_Label=nFAULT
PB13.Signal=GPIO_Input
PB14.GPIO_Label=nSleep
PB14.Signal=GPIO_Output
PB6.GPIO_Label=Enkoder silnika 1 Hall 1
PB6.Signal=S_TIM4_CH1
PB7.GPIO_Label=Enkoder silnika 1 Hall 2
PB7.Signal=S_TIM4_CH2
PB8.GPIO_Label=VL_IRQ
PB8.Signal=GPXTI8
PC5.GPIO_Label=VL_EN1
PC5.Signal=GPIO_Output
PC9.Signal=I2C3_SDA

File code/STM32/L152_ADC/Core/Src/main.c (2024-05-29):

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
/* Includes ------------------------------------------------------------------*/
#include "main.h"
#include "adc.h"
#include "dma.h"
#include "tim.h"
#include "usart.h"
#include "gpio.h"

/* USER CODE BEGIN Includes */
#include <stdio.h>
#include "arm_math.h"
/* USER CODE END Includes */

/* USER CODE BEGIN PD */
#define ADC_BUFF_SIZE 10

#define FIR_LENGTH 461
/* USER CODE END PD */


/* USER CODE BEGIN PV */
float adc_value;
uint16_t adc_buffer[ADC_BUFF_SIZE];

float32_t fir_coefficients[FIR_LENGTH] = { 0.000000000000000000,
    0.000000022609304456, 0.000000092137658127, 0.000000210376981500,
    0.000000378074907886, 0.000000594900325696, 0.000000859416815111,
    0.000001169064300580, 0.000001520149215920, 0.000001907843452345,
    0.000002326192331196, 0.000002768131812358, 0.000003225515116128,
    0.000003689148900478, 0.000004148839097111, 0.000004593446468231,
    0.000005010951901591, 0.000005388531413869, 0.000005712640781930,
    0.000005969109667889, 0.000006143245047260, 0.000006219943689868,
    0.000006183813380806, 0.000006019302503680, 0.000005710837540961,
    0.000005242967976715, 0.000004600518015692, 0.000003768744460037,
    0.000002733500011260, 0.000001481401190987, 0.000000000000000000,
    -0.000001722041638279, -0.000003694775675826, -0.000005926791075647,
    -0.000008425037448593, -0.000011194650419114, -0.000014238780007746,
    -0.000017558423373286, -0.000021152263307200, -0.000025016513915877,
    -0.000029144774962341, -0.000033527896366957, -0.000038153854386003,
    -0.000043007640996822, -0.000048071168018069, -0.000053323187482591,
    -0.000058739229758206, -0.000064291560877524, -0.000069949160491469,
    -0.000075677721802043, -0.000081439674757675, -0.000087194233709117,
    -0.000092897470625088, -0.000098502414854722, -0.000103959180298482,
    -0.000109215120710603, -0.000114215013704846, -0.000118901273871578,
    -0.000123214195238642, -0.000127092223121715, -0.000130472255212696,
    -0.000133289971547970, -0.000135480192783221, -0.000136977265978890,
    -0.000137715476871664, -0.000137629487373880, -0.000136654796805819,
    -0.000134728225127145, -0.000131788416194798, -0.000127776358837126,
    -0.000122635923299772, -0.000116314410389517, -0.000108763110419883,
    -0.000099937868848572, -0.000089799655293773, -0.000078315132425799,
    -0.000065457221054363, -0.000051205657571931, -0.000035547539771790,
    -0.000018477856937501, 0.000000000000000000, 0.000019873752518615,
    0.000041121777108205, 0.000063712680780720, 0.000087604913846630,
    0.000112746424287725, 0.000139074357997619, 0.000166514809072417,
    0.000194982624214208, 0.000224381265158973, 0.000254602732857888,
    0.000285527556926846, 0.000317024853633430, 0.000348952455414073,
    0.000381157114607204, 0.000413474783751794, 0.000445730974435899,
    0.000477741196287834, 0.000509311477285098, 0.000540238966114795,
    0.000570312616856111, 0.000599313955772492, 0.000627017929501001,
    0.000653193833411438, 0.000677606318380946, 0.000700016473693936,
    0.000720182983235291, 0.000737863351600188, 0.000752815196199786,
    0.000764797600901996, 0.000773572526213876, 0.000778906270490711,
    0.000780570976149873, 0.000778346174378884, 0.000772020361360302,
    0.000761392598594556, 0.000746274129489374, 0.000726490004004188,
    0.000701880702793345, 0.000672303751986134, 0.000637635319477743,
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

};

arm_fir_instance_f32 fir_instance;
float32_t fir_in, fir_out, fir_state[FIR_LENGTH];
/* USER CODE END PV */

void SystemClock_Config(void);
/* USER CODE BEGIN 0 */
void HAL_ADC_ConvCpltCallback(ADC_HandleTypeDef *_hadc) {

  uint32_t adc_sum = 0;
  uint8_t i;
  for (i = 0; i < ADC_BUFF_SIZE; i++)
    adc_sum += adc_buffer[i];

  adc_value = adc_sum * 3.3f / 4095.0f / ADC_BUFF_SIZE;

  HAL_GPIO_TogglePin(LD2_GPIO_Port, LD2_Pin);

  fir_in = (float32_t) adc_value;
  arm_fir_f32(&fir_instance, &fir_in, &fir_out, 1);
}

void HAL_TIM_PeriodElapsedCallback(TIM_HandleTypeDef *htim) {

}
/* USER CODE END 0 */

/**
 * @brief  The application entry point.
 * @retval int
 */
int main(void) {

  /* USER CODE BEGIN 1 */
  arm_fir_init_f32(&fir_instance, FIR_LENGTH, fir_coefficients, fir_state, 1);

  float32_t a[] = { 1.0f, 1.0f };
  float32_t a_amp = 0;

  arm_cmplx_mag_f32(a, &a_amp, 1);
  /* USER CODE END 1 */

  /* MCU Configuration--------------------------------------------------------*/

  /* Reset of all peripherals, Initializes the Flash interface and the Systick. */
  HAL_Init();

  /* Configure the system clock */
  SystemClock_Config();

  /* Initialize all configured peripherals */
  MX_GPIO_Init();
  MX_DMA_Init();
  MX_USART2_UART_Init();
  MX_ADC_Init();
  MX_TIM9_Init();
  /* USER CODE BEGIN 2 */
  HAL_TIM_Base_Start(&htim9);
  HAL_UART_Transmit(&huart2, (uint8_t*) "STARTED\r\n", 9, HAL_MAX_DELAY);
  HAL_ADC_Start_DMA(&hadc, (uint32_t*) adc_buffer, ADC_BUFF_SIZE);
  /* USER CODE END 2 */

  /* Infinite loop */
  /* USER CODE BEGIN WHILE */
  uint32_t uart_delay = HAL_GetTick();
  uint32_t line_counter = 0;
  while (1) {
    if (HAL_GetTick() - uart_delay > 1000) {

      uint8_t data[255];
      uint8_t len = sprintf((char*) data, "{%ld} {ADC:%f}\r\n", line_counter++,
          adc_value);
      HAL_UART_Transmit(&huart2, data, len, HAL_MAX_DELAY);

      uart_delay = HAL_GetTick();
    }

    /* USER CODE END WHILE */

    /* USER CODE BEGIN 3 */
  }
  /* USER CODE END 3 */
}

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


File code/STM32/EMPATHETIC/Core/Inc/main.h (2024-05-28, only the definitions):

#define Enkoder_silnika_2_Hall_1_Pin GPIO_PIN_0
#define Enkoder_silnika_2_Hall_1_GPIO_Port GPIOA
#define Enkoder_silnika_2_Hall_2_Pin GPIO_PIN_1
#define Enkoder_silnika_2_Hall_2_GPIO_Port GPIOA
#define DEBUG_Pin GPIO_PIN_3
#define DEBUG_GPIO_Port GPIOA
#define VL_EN1_Pin GPIO_PIN_5
#define VL_EN1_GPIO_Port GPIOC
#define nFAULT_Pin GPIO_PIN_13
#define nFAULT_GPIO_Port GPIOB
#define nSleep_Pin GPIO_PIN_14
#define nSleep_GPIO_Port GPIOB
#define Enkoder_silnika_1_Hall_1_Pin GPIO_PIN_6
#define Enkoder_silnika_1_Hall_1_GPIO_Port GPIOB
#define Enkoder_silnika_1_Hall_2_Pin GPIO_PIN_7
#define Enkoder_silnika_1_Hall_2_GPIO_Port GPIOB
#define VL_IRQ_Pin GPIO_PIN_8
#define VL_IRQ_GPIO_Port GPIOB
#define VL_IRQ_EXTI_IRQn EXTI9_5_IRQn

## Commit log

2023-08-09 init kicad project for bottom board. add motor symbol
    [bottom.kicad_pcb, bottom.kicad_sch, magnetic-encoder-pair-kit-for-micro-metal-gearmotors-hpcb-compatible-enc03b.step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]
2023-08-10 add ball caster footprint
    [pololu-ball-caster-with-0-375in-ball.step]
2023-08-10 move kicad to v7. add wheel model. add wheel to motor footprint
    [pololu-wheel-32x7mm-black.step]
2023-08-11 created freecad sketch for bottom pcb shape
    [shape.FCStd, shape.dxf]
2023-08-13 changed pcb shape dimensions. imported shape into pcb
    [bottom.kicad_pcb, bottom.kicad_sch, shape.FCStd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]
2023-08-13 add drv8833 - motor driver
    [bottom.kicad_sch]
2023-08-22 add ultrasound model, footprint and symbol. add motor driver to schematic for learning kicad
    [bottom.kicad_pcb, bottom.kicad_sch, ultrasound.step]
2023-08-23 add example stm32 uC, add simple footprint for step-up board
    [bottom.kicad_pcb, bottom.kicad_sch, shape.FCStd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]
2023-08-29 small updates on parts
    [bottom.kicad_sch]
2023-08-29 add bno055 - acc ic
    [bottom.kicad_sch]
2023-08-30 small schematic fixes (NC)
    [bottom.kicad_sch]
2023-09-04 add vl53l0x proximity/distance sensor
    [bottom.kicad_pcb, vl53l0x.stp]
2023-09-05 fix vl53l0x 3d model
    [bottom.kicad_pcb, vl53l0x.stp]
2023-09-05 add vl53l0x to schematic, connect footprint to sensors symbol
    [bottom.kicad_pcb, bottom.kicad_sch]
2023-09-05 change vcc and vdd symbols. add routes for bno055 sensor on pcb
    [bottom.kicad_pcb, bottom.kicad_sch]
2023-09-05 divided drv8833 and uC to separate sections
    [bottom.kicad_sch]
2023-09-06 add 18650 samsung li ion battery to 3d preview
    [INR18650-35E-Samsung.STEP, bottom.kicad_pcb]
2023-09-06 add battery connector
    [bottom.kicad_pcb, bottom.kicad_sch]
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2023-09-17 add dw01 and its mosfets to schematic and pcb
    [bottom.kicad_pcb, bottom.kicad_sch]
2023-09-18 wired dw01 and 4x 8205a mosfets
    [bottom.kicad_pcb, bottom.kicad_sch]
2023-09-18 add S7V8F3 step up/down 3.3v regulator
    [pololu-step-up-step-down-voltage-regulator-s7v8fx.step]
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2023-09-19 add 3d model to bq24250 footprint
    [BQ24250RGER.stp]
2023-09-28 switch to stm32f303re uC
    [bottom.kicad_sch]
2023-09-28 initial stm and its elements placement
    [bottom.kicad_pcb, bottom.kicad_sch]
2023-09-28 add solder pads to motor footprint for soldering it to pcb
    [bottom.kicad_pcb]
2023-10-17 fix footprints 3d models paths
    [bottom.kicad_pcb]
2023-10-17 Add current render to readme. Fix some footprint 3d model paths problems
    [bottom.kicad_pcb, bottom.kicad_sch]
2023-10-17 clean old env path variables
    [bottom.kicad_pcb]
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2023-11-10 add pcb shape with holes for 3d printing prototype
    [shape_with_mount_holes.FCStd]
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2023-11-23 add tp5100 li ion charger module
    [bottom.kicad_pcb, tp5100.step]
2023-11-23 add copper pads for charging
    [bottom.kicad_pcb]
2023-11-27 add mounting holes and acs712 current sensors to schematic
    [bottom.kicad_sch]
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2023-11-28 add all modules to pcb (except termometer)
    [bottom.kicad_pcb]
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2023-11-28 add S7V8F3 symbol, footprint. add S7V8F3 to schematic
    [bottom.kicad_sch]
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2023-11-28 add U3V70F5 symbol and footprint. add it to schematic
    [bottom.kicad_sch]
2023-11-28 add batt_prot symbol. clean schematic
    [bottom.kicad_pcb, bottom.kicad_sch]
2023-11-28 changed uC to STM32H7A3RIT6
    [bottom.kicad_sch]
2023-11-29 changed tp5100 footprint to smd. add wiring for li-ion protection and charging
    [bottom.kicad_pcb, bottom.kicad_sch]
2023-11-29 wired motors
    [bottom.kicad_pcb, bottom.kicad_sch]
2023-11-29 prepare to wire distance sensors
    [bottom.kicad_pcb]
2023-11-30 wired laser sensors
    [bottom.kicad_pcb, bottom.kicad_sch]
2023-11-30 move pcb to 4 layer. prewire all elements except signals to drv, encoders
    [bottom.kicad_pcb, bottom.kicad_sch]
2023-12-01 wired sensors to uC. missing bno_irq and i_motor_ab
    [bottom.kicad_pcb, bottom.kicad_sch]
2023-12-01 wired rest. missing rpi connector and proper battery connectors
    [bottom.kicad_pcb, bottom.kicad_sch]
2023-12-02 add simplified programming header for stm32
    [bottom.kicad_pcb, bottom.kicad_sch]
2023-12-02 add uart header for rpi
    [bottom.kicad_pcb, bottom.kicad_sch]
2023-12-05 add ark connector and fix traces
    [ark_conn.step, bottom.kicad_pcb, bottom.kicad_sch]
2023-12-06 fix ark model and 5V trace
    [bottom.kicad_pcb]
2023-12-07 fix ark model and gnd trace
    [bottom.kicad_pcb]
2023-12-09 minor routes optimisation
    [bottom.kicad_pcb]
2024-01-02 changed all blind vias to through vias (cost reduction). minor improvements. add two backup pins pads
    [bottom.kicad_pcb, bottom.kicad_sch]
2024-01-03 move power connector away from ball caster
    [bottom.kicad_pcb]
2024-01-03 moved components description for better visibility
    [bottom.kicad_pcb]
2024-02-21 fix label c27
    [bottom.kicad_pcb]
2024-02-21 add 3.3v to programming header
    [bottom.kicad_pcb, bottom.kicad_sch]
2024-02-21 add text for charging pad+
    [bottom.kicad_pcb]
2024-02-21 fix drv8833 wrong vint cap connection. connect nSleep pin to uC
    [bottom.kicad_pcb, bottom.kicad_sch]
2024-02-21 change j4 power connector orientation
    [bottom.kicad_pcb, bottom.kicad_sch]
2024-02-24 fix motors pinout
    [bottom.kicad_pcb, bottom.kicad_sch]
2024-02-24 add additional vias for motor pins
    [bottom.kicad_pcb]
2024-03-07 fix traces
    [bottom.kicad_pcb]
2024-03-12 make motor pad bigger
    [bottom.kicad_pcb]
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2024-03-28 add test adc project for l152 (oversampling, timer trigger, dma)
    [L152_ADC.cfg]
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2024-04-24 add 3d models of utility elements
    [battery.scad, battery.stl, led.scad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]
2024-04-28 tilt camera mount and widen clearance for bending camera ribbon cable
    [rpi_board.scad, rpi_board.stl]
2024-05-21 add holes to rpi_board model for cables
    [rpi_board.scad, rpi_board.stl]
2024-05-28 add draft of a charger station
    [charger.scad, charger.stl]
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2024-05-31 add RL ROS simulator
    [common_properties.xacro, lidar.xacro, mobile_base.xacro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]
2024-06-03 add timer to measure elapsed time of experiment. fix ray inaccuracies bug
2024-06-05 add files for digital filter coefs and init state
    [enc_A_LPF_coeffs.csv, enc_A_LPF_state_init.csv, enc_B_LPF_coeffs.csv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]

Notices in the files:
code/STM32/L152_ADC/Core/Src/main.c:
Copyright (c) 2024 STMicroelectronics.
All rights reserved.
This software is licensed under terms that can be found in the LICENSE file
